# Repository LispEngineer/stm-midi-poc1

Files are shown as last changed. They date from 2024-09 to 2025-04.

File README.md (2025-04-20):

# MIDI Synthesizer Proof of Concept 1

**Feedback is very welcome!**

* Author: [Douglas P. Fields, Jr.](mailto:symbolics@lisp.engineer)
* My portions Copyright 2024 Douglas P. Fields, Jr.
* My portions License: Creative Commons Attribution-ShareAlike 4.0
  * AKA `CC BY-SA 4.0`
  * [See LICENSE.md](LICENSE.md) or [CC site](https://creativecommons.org/licenses/by-sa/4.0/deed.en)
* Started 2024-09-28
* Last updated 2025-04-20
* [Repo Self-Link](https://github.com/LispEngineer/stm-midi-poc1)

Overviews:
* 3D Views
  * Front 3D View
  * Rear 3D View
* [Schematic PDF](stm-midi-poc1.pdf)
* [Board Plots as PDF](plots/stm-midi-poc1__Assembly.pdf)
  * From Board2PDF KiCAD Plugin
* [Interactive BOM](bom/ibom.html)
  * From Interactive BOM KiCAD Plugin

Design documents:
* [Design notes](Design.md)
* Designed in [KiCAD 8](https://www.kicad.org/)
* LCSC part numbers included for assembly by [JLCPCB](https://jlcpcb.com/)

Debuggers:
* Segger J-Link EDU Mini
* Segger J-Link Plus v10.1 (second hand)
  * Built in VCOM port - only seems to work at 115,200 baud
* ST-Link v3
* FTDI USB to TTL UART

Software:
* [Pinout](https://github.com/LispEngineer/stm-midi-poc1-sw)
* [STM Synth](https://github.com/LispEngineer/nucleo-uart)
* [My KiCAD Libraries](https://github.com/LispEngineer/KiCAD_Libraries)

Discussions:
* [Smaller Optoisolator](https://www.reddit.com/r/synthdiy/comments/1gghujj/smaller_midi_optoisolator/)

## Key Reference Documents

* [DS11853](TODO) - Datasheet: Arm® Cortex®-M7 32b MCU+FPU, 462DMIPS, up to 512KB Flash
  256+16+4KB RAM, USB OTG HS/FS, 18 TIMs, 3 ADCs, 21 com IF
* [RM0431](TODO) - STM32F72xxx ... advanced Arm®-based 32-bit MCUs
* [PM0253](TODO) - STM32F7 Series ... Cortex®-M7 processor programming manual
* [ES0360](TODO) - STM32F72xxx ... device limitations
* [AN2867](TODO) - Guidelines for oscillator design on ... STM32 MCUs/MPUs
* [AN4661](TODO) - Getting started with STM32F7 Series MCU hardware development
* [AN5612](TODO) - ESD protection of STM32 MCUs
* [AN4879](TODO) - Introduction to USB hardware and PCB guidelines using STM32 MCUs
* [AN4989](TODO) - STM32 microcontroller debug toolbox
* [AN4676](TODO) - STM32F7 Series peripheral interconnections
* [AN4031](TODO) - Using the STM32F2, STM32F4 and STM32F7 Series DMA controller

Moving to STM32H7:
* [AN5293](TODO) - Migration guide from STM32F7 Series to STMH74x/75x, STM32H72x/73x and STMH7A3/7Bx devices
* [AN4936](TODO) - Migration of microcontroller applications from STM32F7 Series to STM32H743/753 line

# Production Runs

I have been using JLCPCB.

* [JLCPCB instructions](https://jlcpcb.com/help/article/how-to-generate-gerber-and-drill-files-in-kicad-8)
  on creating Gerber and Drill files for KiCAD 8.
* You can also use the
  [JLCPCB KiCAD plugin](https://github.com/Bouni/kicad-jlcpcb-tools).
  * Installed using the *Plugin and Content Manager* in KiCAD.
  * This usefully shows you the stock count for your parts, and whether
    they are Basic or Extended.
  * Current version (2024-12-21) gives a lot of errors about redundant
    parts already in the catalog though (annoying).
* Or maybe I was using [this JLCPCB KiCAD plugin](https://github.com/bennymeg/Fabrication-Toolkit).

## Run 1 - EVT#1

* Submitted: 2024-10-27
* Git Commit: `6f9e281abe9c22ef3b995376c3df42217fc04524`
* Producer: JLCPCB
  * Order #W202410271206812 
* Boards: 5
* Assemblies: 2
* [BOM](jlcpcb/production_files/BOM-stm-midi-poc1.csv)
* [CPL](jlcpcb/production_files/CPL-stm-midi-poc1.csv)
* [Gerbers](jlcpcb/production_files/GERBER-stm-midi-poc1.zip)
* JLCPCB Corrected Part Placement
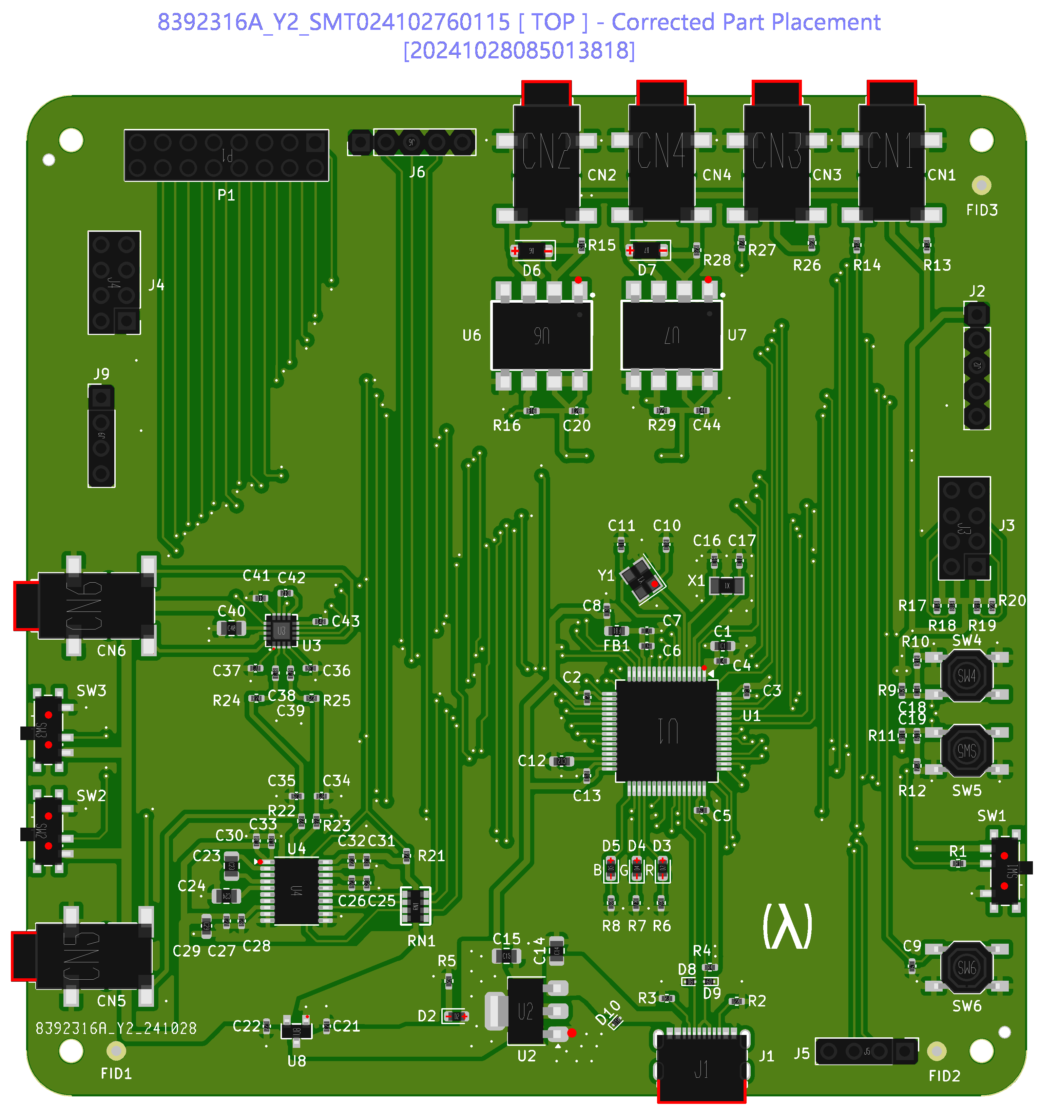
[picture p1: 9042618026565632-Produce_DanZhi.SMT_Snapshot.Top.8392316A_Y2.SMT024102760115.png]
  
* [JLCPCB Submission](jlcpcb-production/run1-20241027/stm-midi-poc1 6f9e281abe9c22ef3b995376c3df42217fc04524_Y2.zip)
* Status: Production complete; in DHL's hands for delivery Nov 8
* Cost:
  * PCB: $28.02
  * Assembly: $79.66
  * Shipping: $32.60 (DHL)
  * Sales tax: $11.22
  * Total: $151.50

I received two fully populated boards. One was missing the J5 header.

EVT1 Front Picture

## Run 2 - EVT#2

* Submitted: 2024-12-21 (11PM NYC time)
  * PCB and PCBA confirmed: 2024-12-22
* Git Commit: `e48a22093a1c81bb14c9082240e3d44837e7d75e`
* Producer: JLCPCB
* Order #W202412221204947 
* Boards: 5
* Assemblies: 2
* [BOM](jlcpcb/production_files/BOM-stm-midi-poc1.csv)
* [CPL](jlcpcb/production_files/CPL-stm-midi-poc1.csv)
* [Gerbers](jlcpcb/production_files/GERBER-stm-midi-poc1.zip)
* JLCPCB Corrected Part Placement
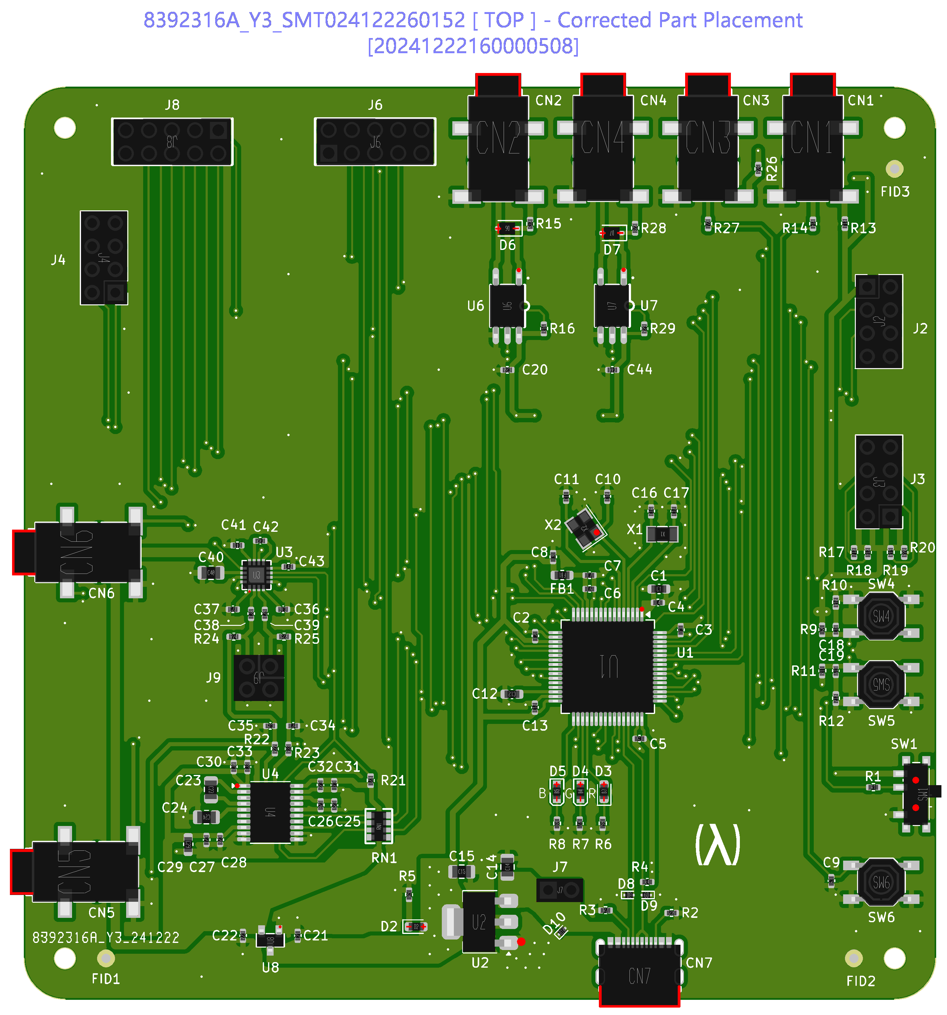
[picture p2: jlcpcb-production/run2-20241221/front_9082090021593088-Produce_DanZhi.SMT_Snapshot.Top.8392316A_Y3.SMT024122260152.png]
JLCPCB Corrected Part Placement
  
* [JLCPCB Submission](jlcpcb-production/run2-20241221/GERBER-stm-midi-poc1_Y3.zip)
* Status: Confirmed for PCB/PCBA
* Cost:
  * PCB: $8.00
  * Assembly: $86.40
  * Shipping: $58.36 (FedEx - "remote area" charge)
  * Sales tax: $12.22
  * Total: $164.98
* Received: 2025-01-03 (delivered on 2025-01-02)

Results:
* They did not add assembly holes this time (interesting, maybe re-used the mounting holes)
* STM32 Debugger (ST-Link v3) does not seem to reliably connect anymore.
  * It did allow me to download the firmware but is not reliable.
  * Sometimes it says "Failed to enable Live Expressions"
* SPI display works
* Audio Gain pins work
* Audio mute works
* Headphone output works
* Buttons & LEDs work

TODO:
* Test MIDI in/out
* Test Line out
* Test various resistors for the headphone
* Test I2C
* Test GPIO

# Miscellaneous Notes

* Footprints, models, etc., by their respective authors
* Some footprints, schematics, models are from these sources:
  * [Component Search Engine](https://componentsearchengine.com)
  * [Snap EDA](https://snapeda.com)
  * [EasyEDA](https://easyeda.com)
* Useful tools:
  * [EasyEDA2KiCAD](https://github.com/uPesy/easyeda2kicad.py)
  * [JLC Parts Finder](https://yaqwsx.github.io/jlcparts/)
  * [Altium Viewer](https://www.altium365.com/viewer/)
    * If you have Altium files and want to get details out of them
      but only use KiCAD

# KiCAD Configuration Notes

Using EasyEDA2KiCAD:

* Create a Path Substitution
  * Use main KiCAD window: Prefernces -> Configure Paths...
  * `EASYEDA2KICAD`
  * [Git Repository](https://github.com/LispEngineer/KiCAD_Libraries)
* Create a Footprint Library
  * `easyeda2kicad` Nickname
  * `${EASYEDA2KICAD}/easyeda2kicad.pretty`
* Create a Symbol Library
  * `easyeda2kicad` Nickname
  * `${EASYEDA2KICAD}/easyeda2kicad.kicad_sym` Library Path

# Status

* Schematic: Done
* LCSC part IDs: Almost Done
  * Need non-Red LEDs
* Schematic symbols: Done
* Footprints: Done
* 3D models: Done
* PCB Layout: Done
* Production 1 run: Done - in shipping

## TODOs

* Use STDC14 connector for ST-Link v3
  * Digikey [1175-1632-ND](https://www.digikey.com/en/products/detail/cnc-tech/3220-14-0300-00/3883270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)
    * Not in JLCPCB
  * Mouser [SHF-107-01-L-D-SM](https://www.mouser.com/ProductDetail/Samtec/SHF-107-01-L-D-SM?qs=%252BZP6%2F%252BtExtBY5XT826bN4g%3D%3D)
    * [Footprint](https://kinetictest.samtec.com/partnumber/shf-107-01-l-d-sm#featureinformation)
    * [JLCPCB C17640678](https://jlcpcb.com/partdetail/Samtec-SHF_107_01_L_DSM/C17640678) - $2???
    * [LCSC Alternative 1](https://www.lcsc.com/product-detail/Pin-Headers_Hanbo-Electronic-Hanbo-Electronic-HB-PH9-12727PB2GOB_C6332251.html) C6332251
    * [LCSC Alternative 2](https://www.lcsc.com/product-detail/Pin-Headers_HCTL-HCTL-PZ127-2-07-S_C3975190.html) C3975190 - 11¢
    * [LCSC Alternative 3](https://www.lcsc.com/product-detail/Pin-Headers_XKB-Connection-XKB-Connection-X1321WVS-2x07J-C40D53_C2881912.html) C2881912
* Use a 4-pin 32kHz clock?
* RN1 footprint and 3D model look a little bit off - footprint is a bit too small?
* Test points/pins
* MCU Pin 24 is not used - it is I2S1_MCK
* Incorporate my own ST-Link?
  * [See Hackaday](https://hackaday.io/project/179054-custom-st-link-v20-v21-v30)

### DONE

* DONE(EVT2): Find a much smaller Opto-isolator for MIDI than the one chosen here
  * [TLP2362](https://toshiba.semicon-storage.com/us/semiconductor/product/isolators-solid-state-relays/detail.TLP2362.html)
    is used by [Ksoloti 0.6](https://ksoloti.github.io/5-resources.html). Tested to work with
    1.8kΩ pull-up resistor instead of the schematic's 2.7kΩ.
    (Also worked with no pull-up resistor!)

# Board Layout Notes

4-layer design with Signal/GND/GND/Signal for EVT board.

Will do most important routing first on the top copper layer:
* Decoupling/bypass capacitors
* Clock signals
* High speed signals
  * USB
  * DAC
  * SWD

Remaining signals will be routed using "Manhattan routing."
That is, one signal layer will run up/down, the other will
run left/right, mostly.
* Top layer: up/down
* Bottom layer: left/right

After that, do these routings:
* Audio signals
* MIDI signals
* SPI
* I²C
* UI (Buttons, LEDs)
* GPIO
* Power

Fill in some positive power areas with fill.

Finally, the signal layers will be filled with GND at the end,
and the ground planes should be stitched together with lots
of vias.

## After Layout Is Done

* DRC check
* Cleanup Tracks & Vias

# BOM Notes

* Docs say you need a 4.7 uF ceramic capacitor with low ESR DS11853 Rev 9 page 105
  * Samsung CL10A475KO8NNNC works *but* Datasheet doesn't say what the ESR is, just "low ESR"
  * [Notes on the Cap](https://community.st.com/t5/stm32-mcus-products/how-supply-stm32f446ret6/td-p/635424)

* [ISOM8710](https://www.ti.com/product/ISOM8710) 
  is a drop-in replacement for the
  [TLP2362](https://toshiba.semicon-storage.com/us/semiconductor/product/isolators-solid-state-relays/detail.TLP2362.html)
  * Same form factor
  * Same functionality (tested on a breadboard)
  * Same circuit
  * Does not seem to be carried at JLCPCB

# Notes for future

* Use fewer header types, they're all extended parts
* Don't use the Resistor Network - due to the Extended parts fee from JLC
  * OTOH there are no 56Ω resistors in the Basic parts library
  * C25127 is an extended part 0402
  * C17714 is an 0805 47Ω
* Add I/O activity LEDs for MIDI & serial?
* Add a pin for VBUS (5V from USB) and USB GND
* Add pins for the TRS jacks
* Get a 4-way switch for gain?
* Rewrire the headphone amp like Pimoroni?
* Move console from UART3 to UART2
  * Move console pins next to SWD pins for easy use with STLink
* Install UART to USB bridge
  * [FTDI FT234XD](https://ftdichip.com/products/ft234xd/) is a nice 12-pin package
  * [Example Circuit](https://github.com/z4yx/USB-C-Serial)
  * [JLCPCB Part](https://jlcpcb.com/partdetail/Ftdi-FT234XDR/C132158)

Longer term
* Move to an STM32H7 device
* Move to a [higher pin-count device](https://www.st.com/en/microcontrollers-microprocessors/stm32h7-series/products.html)
  * LQFP 64, 100, 144, 176, 208
    * low-profile quad flat package - LQFP 64 currently in use
  * TFBGA 216, 225, 240+25
    * Thin Profile Fine Pitch Ball Grid Array
    * thinner than other BGA packages - Gemini
  * UFBGA 144, 169, 176+25
    * ultra fine pitch ball grid array
  * VFQFPN 68
    * thermally enhanced very thin profile fine pitch quad flat package no lead (Gemini)
  * WLCSP 132, 156
    * [Wafer-Level Chip Scale Packaging](https://www.flashpcb.com/blog/QFP-QFN-BGA-WLSCP)
* Add an SDRAM

# EasyEDA 2 KiCAD Notes

`python -m easyeda2kicad --full --lcsc_id=Cxxxxx`

[My imported library is in GitHub](https://github.com/LispEngineer/KiCAD_Libraries).

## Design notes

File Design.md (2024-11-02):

# Doug's MIDI Synth Board

* [Douglas P. Fields, Jr.](mailto:symbolics@lisp.engineer)
* Copyright 2024, Douglas P. Fields, Jr.
* License: Creative Commons Attribution-ShareAlike 4.0
  * AKA `CC BY-SA 4.0`
  * [See LICENSE.md](LICENSE.md) or [CC site](https://creativecommons.org/licenses/by-sa/4.0/deed.en)

Project Documentation:
* [Hardware requirements](https://docs.google.com/document/d/1ovH1onACyaObaqHR-o14pt8njggKNDry9VQSeMS2iqw/edit#heading=h.xvwzye5fndkg)

STM Hardware Development:
* [AN4661 Getting started with STM32F7 Series MCU hardware development](https://www.st.com/resource/en/application_note/an4661-getting-started-with-stm32f7-series-mcu-hardware-development-stmicroelectronics.pdf)
* [AN4938 Getting started with STM32H7{4,5}xI/G MCU hardware development](https://www.st.com/resource/en/application_note/an4938-getting-started-with-stm32h74xig-and-stm32h75xig-mcu-hardware-development-stmicroelectronics.pdf)
* [AN5419 Getting started with STM32H7{2,3}... Line hardware development](https://www.st.com/resource/en/application_note/an5419-getting-started-with-stm32h723733-stm32h725735-and-stm32h730-value-line-hardware-development-stmicroelectronic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)
* [AN4879 USB hardware and PCB guidlines using STM32 MCUs](TODO)
* [AN5225 Introduction to USB Type-C® Power Delivery](TODO)
  * See Section 10 - `Type C with no Power Delivery`

STM Documents:
* [DS11853 Rev 9 - STM32F2{2,3}xx Datasheet](TODO)

STM Discussions:
* [Forum: Recommended schematic review](https://community.st.com/t5/stm32-mcus/how-to-conduct-a-stm32-self-schematic-review-pt-1/ta-p/49593)
  * [Part 2](https://community.st.com/t5/stm32-mcus/how-to-conduct-a-stm32-self-schematic-review-pt-2/ta-p/49595)
* [StackOverflow STM32](https://electronics.stackexchange.com/questions/611915/schematic-review-for-stm32-basic-development-board)
* [STM32 Design in KiCAD](https://vivonomicon.com/2018/05/05/your-own-hardware-designing-an-stm32-development-board/)

Schematic References:
* [Ksoloti Core 0.6](https://github.com/ksoloti/ksoloti)
  * [STM32F429ZGT6 (LQFP 144)](https://www.st.com/en/microcontrollers-microprocessors/stm32f429zg.html#overview) with SDRAM
  * [Schematics](https://ksoloti.github.io/5-resources.html)
* [Daisy Seed](TODO) - schematic not available
* [Teensy 4.1](TODO) - Renesas, not STM32
* [Blue Pill](https://stm32-base.org/boards/STM32F103C8T6-Blue-Pill.html)
  * [More on Blue Pill](https://www.hackster.io/MakerIoT2020/remaking-the-stm32-blue-pill-d3ae30)
* [Pimoroni Pico Audio Pack PIM544](https://shop.pimoroni.com/products/pico-audio-pack?variant=32369490853971)
  * [Pimoroni Pico Audio Pack PIM544 Schematic](https://cdn.shopify.com/s/files/1/0174/1800/files/pico_audio_pack_schematic.pdf?v=1647429199)
  * [PCM5102A I2S DAC](https://www.ti.com/product/PCM5102A)
  * [PCM5102 and STM32](http://elastic-notes.blogspot.com/2020/11/use-pcm5102-with-stm32_76.html)
  * [Wikipedia I²S](https://en.wikipedia.org/wiki/I%C2%B2S)
* [ubld.it MIDI-Mini Breakout Board](https://ubld.it/midi-mini)

# Schematic Notes

* Using STM32F722xx with LQFP64 pinout

* Vbat - See DS11853 Rev 9 - Connect to "VDD when no external battery 
  and [no] external super-capacitor are present."

## USB-C in 2.0 Mode

* [Wiring post](https://www.eevblog.com/forum/projects/usb-type-c-(usb2-0)-wiring/)
  - A6 to B6 (D+) to D+ on the micro
  - A7 to B7 (D-) to D- on the micro
  - A4 to A9 to B4 to B9 (VBUS) to VCC (+5V) on the micro
  - A5 (CC1) to GND via 5k1 Resistor
  - B5 (CC2) to GND via another 5k1 Resistor
  - A1 to A12 to B1 to B12 (GND) to Ground
* [Another wiring post](https://www.eevblog.com/forum/projects/minimal-wiring-for-usb-c-jack/)
* [Kicad Post](https://forum.kicad.info/t/how-to-connect-a-ft232rl-to-a-usb-type-c-connector/18557/2)
* Where is the official specification for this?
* [GND & Shield](https://electrical.codidact.com/posts/279876/285004#answer-285004)

## Power

* [STM LD1117](https://www.st.com/resource/en/datasheet/ld1117.pdf) - 800mA
* [STM LD39050](https://www.st.com/resource/en/datasheet/ld39050.pdf) - 500mA
* [AMS1117-3.3](http://www.advanced-monolithic.com/pdf/ds1117.pdf) - 1A
* [AP2161](https://www.digikey.com/en/products/base-product/diodes-incorporated/31/AP2161/66238)
  * C176957 & C2149802

## Misc Components

* Ferrite Bead: 
* [16 MHz Oscillator](https://jlcpcb.com/partdetail/YangxingTech-X322516MMB4SI/C112972)
* USB-C ESD Protection: STM USBLC6-2
* [32k Crystal Notes](https://community.st.com/t5/stm32-mpus-products/lse-crystal-for-st32mp1-fc-135-38-768-khz/td-p/679119)
  * [Phil's Lab Math](https://youtu.be/aVUqaB0IMh4?t=1619&si=jmx2GFCgxkBLzdWy)
  * Load Capacitors
  * 7pF osc
  * Estimate 3-5pF of stray capacitance
  * 7 - 5 = 2 x 2 = 4 pF
  * 7 - 3 = 4 x 2 = 8 pF
  * 7 - 4 = 3 x 2 = 6 pF
* [Push Button Wiring](https://www.youtube.com/watch?v=JZsC34jfbEg)
* [TRS MIDI](https://midi.org/specification-for-use-of-trs-connectors-with-midi-devices)
* [ubld.it MIDI Breakout Schematic](https://ubld.it/wp-content/uploads/2023/10/MIDI_BOB_MV_Mini_Schematic_RevA.pdf)
* [DeftAudio Teensy MIDI Schematic](blob:https://github.com/08e4b098-b5fc-4c80-bbc1-2535837214dd)
* [Component Search Engine](https://componentsearchengine.com/)
* [JLC Component Catalog](https://yaqwsx.github.io/jlcparts/#/) Third party tool
* Resettable fuse: SMD0603-200L

## Opto-Isolator Alternatives

* [Toshiba TLP2361](https://toshiba.semicon-storage.com/us/semiconductor/product/isolators-solid-state-relays/detail.TLP2361.html)
  * Package: SOIC-6
  * [Mouser](https://www.mouser.com/ProductDetail/Toshiba/TLP2361TPLE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)
  * [LCSC](https://www.lcsc.com/product-detail/Optocouplers---Logic-Output_TOSHIBA-TOSHIBA-TLP2361V4-TPL%2CE_C123773.html)
  * "if you need to save space, use a SO-5 chip like the TLP2361 (which has a CMOS output, so it does not need a pull-up resistor)" [source](https://electronics.stackexchange.com/questions/165255/midi-in-many-circuits)
* [Toshiba TLP2362](https://toshiba.semicon-storage.com/us/semiconductor/product/isolators-solid-state-relays/detail.TLP2362.html)
  * Used by Ksoloti - see their schematic
* [Vishay VO0600](https://www.vishay.com/en/product/84607/)
  * Package: SOIC-8
  * [LCSC](https://www.lcsc.com/product-detail/Logic-Output-Optoisolators_Vishay-Intertech-VO0600T_C5830851.html)
  * [Mouser](https://www.mouser.com/ProductDetail/Vishay-Semiconductors/VO0600T?qs=xCMk%252BIHWTZMQ6VardsKvcQ%3D%3D)
* [TI ISOM8710](https://www.ti.com/product/ISOM8710)
  * Package: SOIC-5
  * [Mouser](https://www.mouser.com/ProductDetail/Texas-Instruments/ISOM8710DFFR?qs=1Kr7Jg1SGW%2Fig%2FeXrQnwtQ%3D%3D)
  * [LCSC](https://www.lcsc.com/product-detail/Modules_Texas-Instruments-ISOM8710DFFEVM_C17217617.html) -
    not currently available
* [TI ISOM8711](https://www.ti.com/product/ISOM8711)
  * Package: SOIC-5
  * [Mouser](https://www.mouser.com/ProductDetail/Texas-Instruments/ISOM8711DFFR?qs=HoCaDK9Nz5f4%252B%2FwLVK60Ow%3D%3D)
  * [LCSC](https://www.lcsc.com/product-detail/Optocoupler-Emulator-Optocoupler-Replacement_Texas-Instruments-ISOM8711DFFR_C22399679.html) - 
    not currently available
* [TI ISOM8110]() - also look at ISOM8115
  * Package: SOIC-4
  * [LCSC](https://www.lcsc.com/product-detail/Optocoupler-Emulator-Optocoupler-Replacement_Texas-Instruments-ISOM8110DFGR_C22431318.html) -
    not currently available
  * [Mouser](https://www.mouser.com/ProductDetail/Texas-Instruments/ISOM8110DFGRQ1?qs=IKkN%2F947nfCR7%2Fv949luTw%3D%3D)
  * [Mouser 8115](https://www.mouser.com/ProductDetail/Texas-Instruments/ISOM8115DFGRQ1?qs=olJun0bQHM8UNDPuYUCEKw%3D%3D)
* [H11L1]()
  * Available in DIP models, e.g., PDIP-6
  * Mouser doesn't stock Everlight models
  * [Mouser OnSemi H11L1M](https://www.mouser.com/ProductDetail/onsemi-Fairchild/H11L1M?qs=P36CEcFBmYxn5ViwkIckpw%3D%3D)
  * Everlight [LCSC](https://www.lcsc.com/product-detail/Logic-Output-Optoisolators_Everlight-Elec-H11L1S-TA_C78589.html) - plenty in stock, SMD

# DF0997 UART/I2C Display

I tested this with an FT-232 and RealTerm on Windows.
[GitHub](https://github.com/DFRobot/DFRobot_LcdDisplay)
has library source code. [Wiki](https://wiki.dfrobot.com/_SKU_DFR0997_I2C_UART_2_inch_Color_Serial_Command_Screen#target_16)
has documentation.

* UART: 9,600 bps 8-N-1
  * I tried 57,600 but it seems fixed at 9,600
* Clear screen: 0x55 0xAA 0x01 0x1D
* Draw a black pixel: 0x55 0xAA 0x0E 0x02 0x00 0x00 0x00 0x00 0x60 0x00 0x60 0xFF 0xFF 0xFF 0xFF 0xFF 0xFF
* Set background color to green: 0x55 0xAA 0x04 0x19 0x00 0xFF 0x00
  * This keeps the various black pixels still black (!)
* If you plug in a USB-C to your Windows computer, it shows up as 
  a USB drive with 8MB capacity
  * Lots of `.png` files in various directories
  * They call this the "U-Disk"

# KiCAD 8 Notes

## Plugins

* [JLC PCB Fabrication Toolkit](https://github.com/bennymeg/Fabrication-Toolkit)
* [KiCAD JLCPCB tools](https://github.com/Bouni/kicad-jlcpcb-tools)
* Alternate Kicad Library
* Generic Symbol Library
* 4ms Kicad Libraries
* Schematic Blocks Plug-In
* Simple Libraries
* Git plugin
* PCBWay
  * Fabrication Toolkit
  * Plug-in for KiCad

## EasyEDA imports

* Use [this tool](https://github.com/uPesy/easyeda2kicad.py)

## Copper Zones

* After placing them, you have to calculate their fills
  before they'll do anything!
  * Hit `b` hotkey

# Git for Windows notes

## Powershell

* `start-ssh-agent.cmd`

# JLCPCB Notes

Using the JLCDFM automated analyzer:

* Silkscreen line width needs to be > 0.15mm
  * This means a lot of letters are too thin by default
* Ensure that silkscreen does not cover any holes
* Have at least 3.05mm from any through hole components to
  SMD components (THT to SMD)
* Slot widths have to be 0.81mm
  * The USB-C slots seem to be 0.6mm
* All Vias are warned as unconnected
* The micro and Ohm unicode symbols do not import into JLCPCB BOM properly

KiCAD 8 notes:
* Create a special field for JLCPCB manufacturing:
  * File -> Schematic Setup → General → Field Name Templates
  * LCSC - JLC PCB Part number
  * DPFNOTES - Doug's notes on the part
  * DPFURL - URL to a spec sheet on the part

Utilities:
* [Component Catalog](https://yaqwsx.github.io/jlcparts/#/) - 3rd party site
* [Importer](https://forum.kicad.info/t/post-v7-new-features-and-development-news/40144/29)
* [EasyEDA loader](https://forum.kicad.info/t/footprints-from-jlcpcb/47051/8)

# JLCPCB Components

Components:
* [STM32F722RET6](https://jlcpcb.com/partdetail/Stmicroelectronics-STM32F722RET6/C118207)
  * LCSC C118207
* [Mini pushbutton](https://jlcpcb.com/partdetail/XkbConnection-TS_1187A_B_AB/C318884)
  * Mfr TS-1187A-B-A-B XKB
  * LCSC C318884
* [32k Crystal](https://jlcpcb.com/partdetail/SeikoEpson-Q13FC13500004/C32346)
  * LCSC C32346

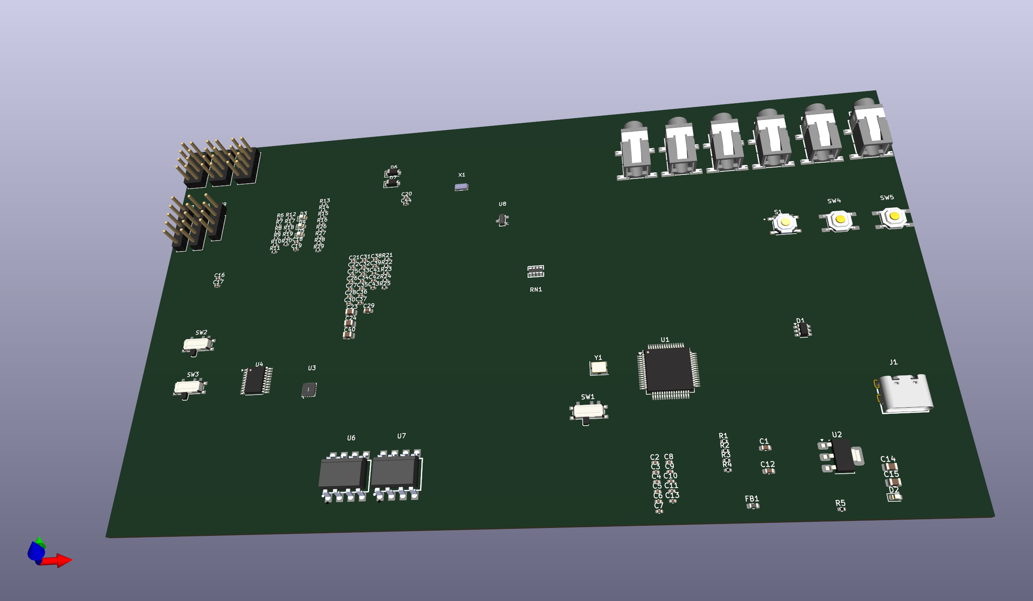
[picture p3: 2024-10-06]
stm-midi-poc1-pcb1.png

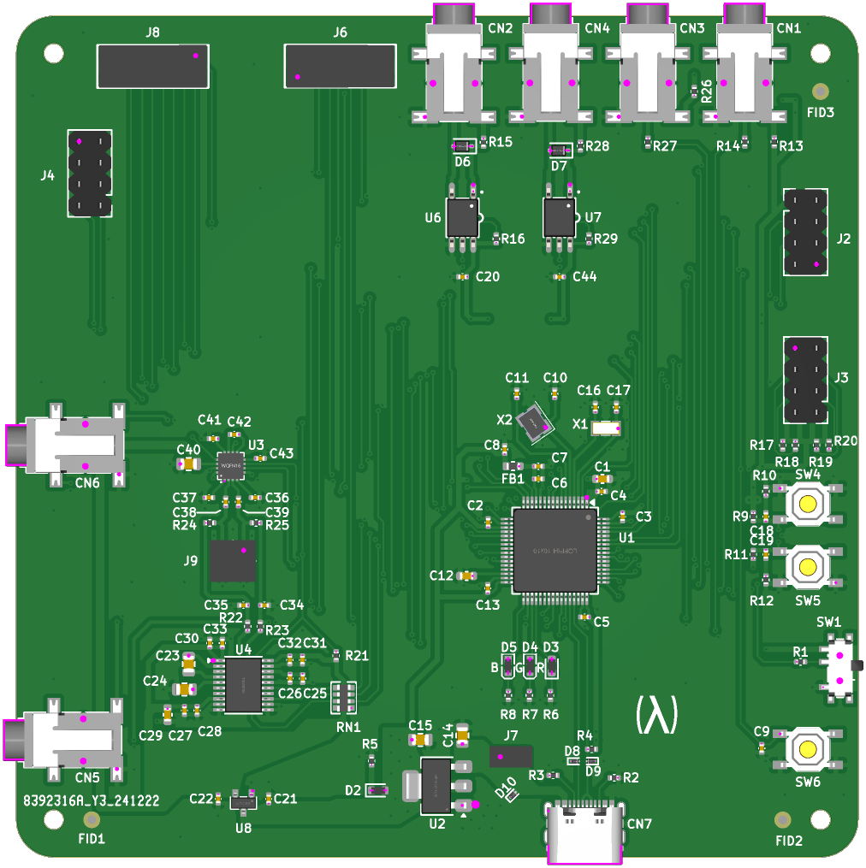
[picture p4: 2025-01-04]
top_12_22_2024, 10_15_21 AM.png

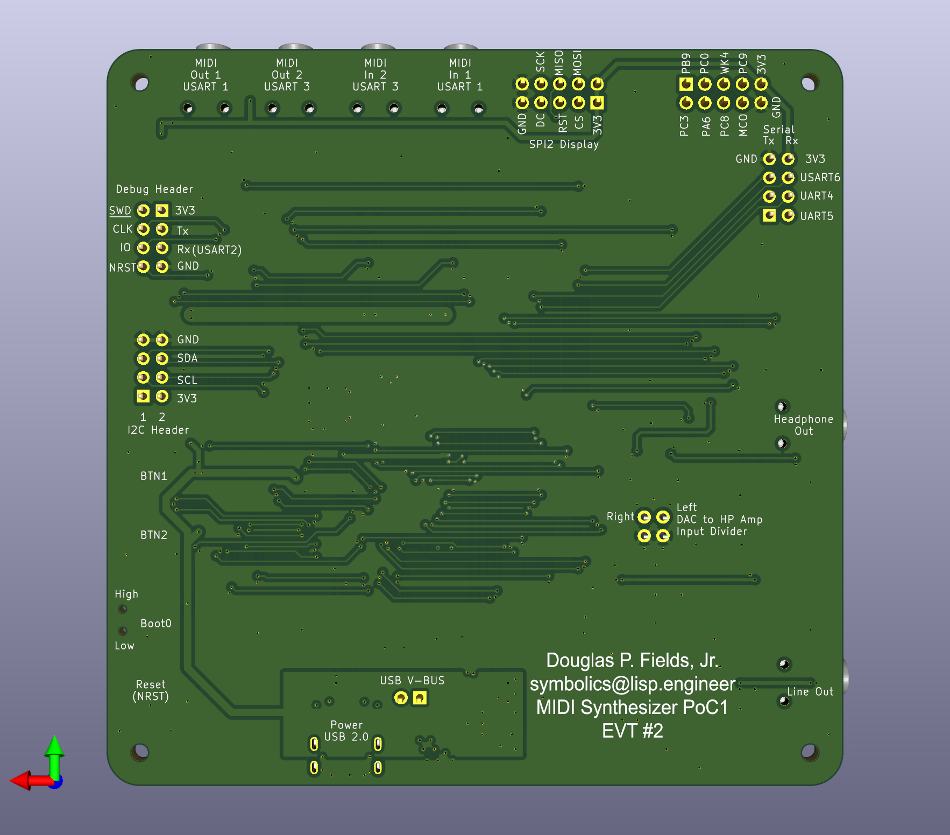
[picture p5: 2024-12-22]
stm-midi-poc1-3d-rear-head-on.png

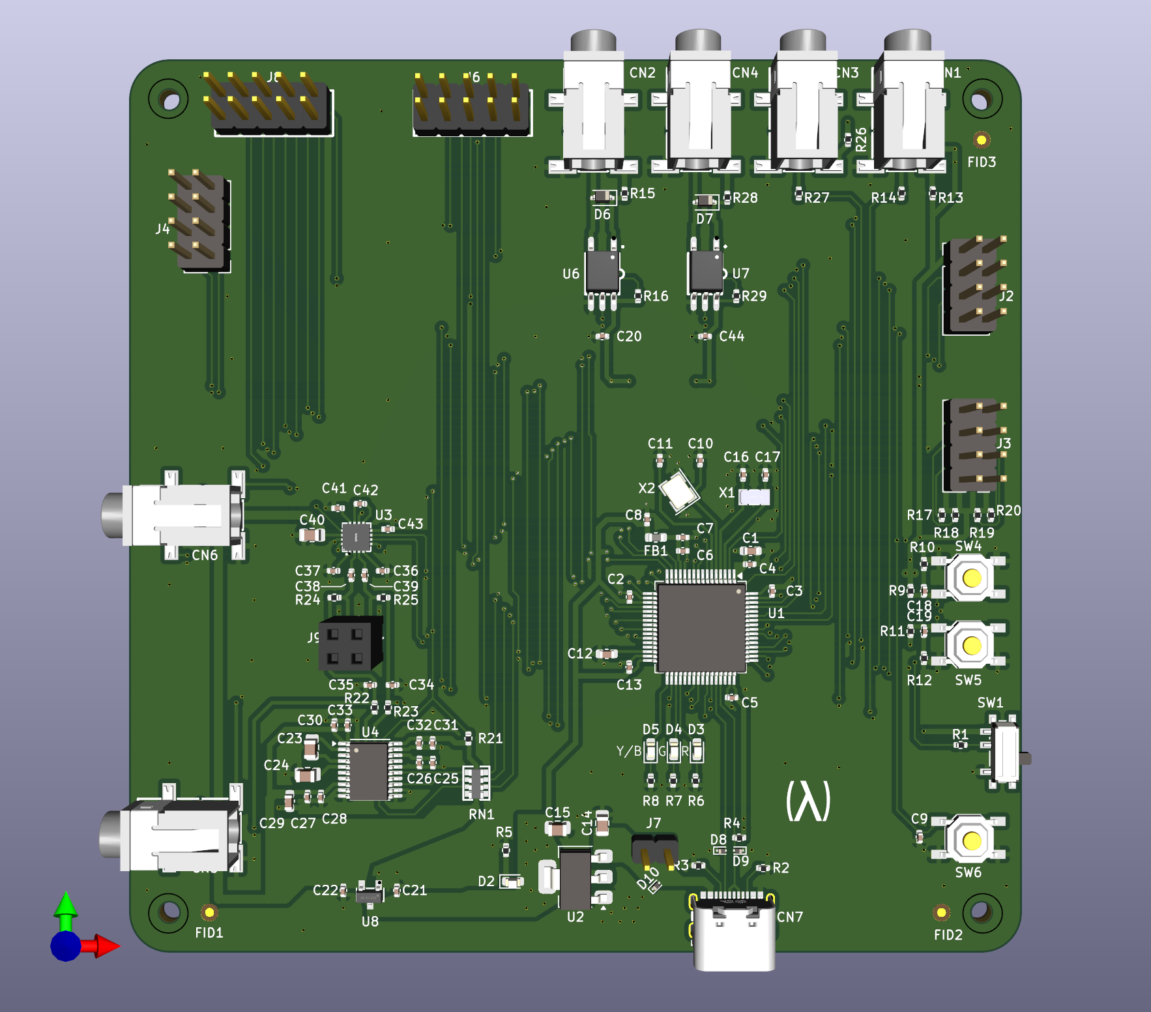
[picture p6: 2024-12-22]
stm-midi-poc1-3d-front-head-on.png

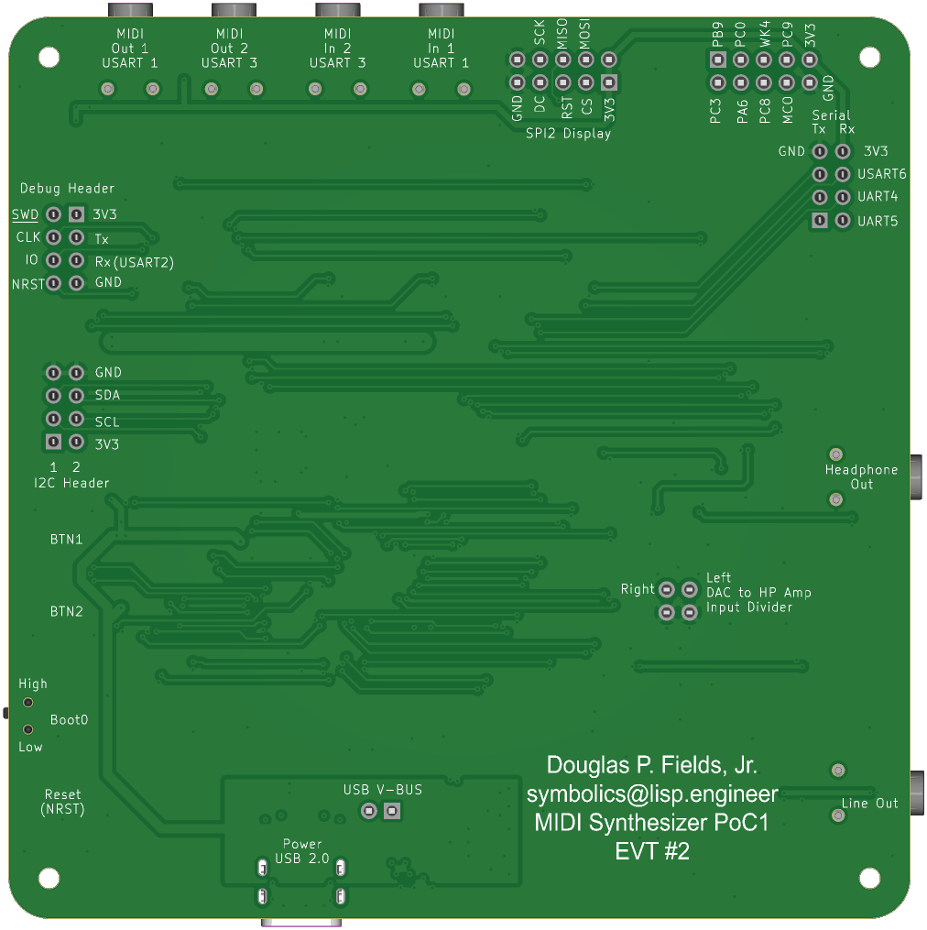
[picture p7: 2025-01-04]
bottom_12_22_2024, 10_15_21 AM.png

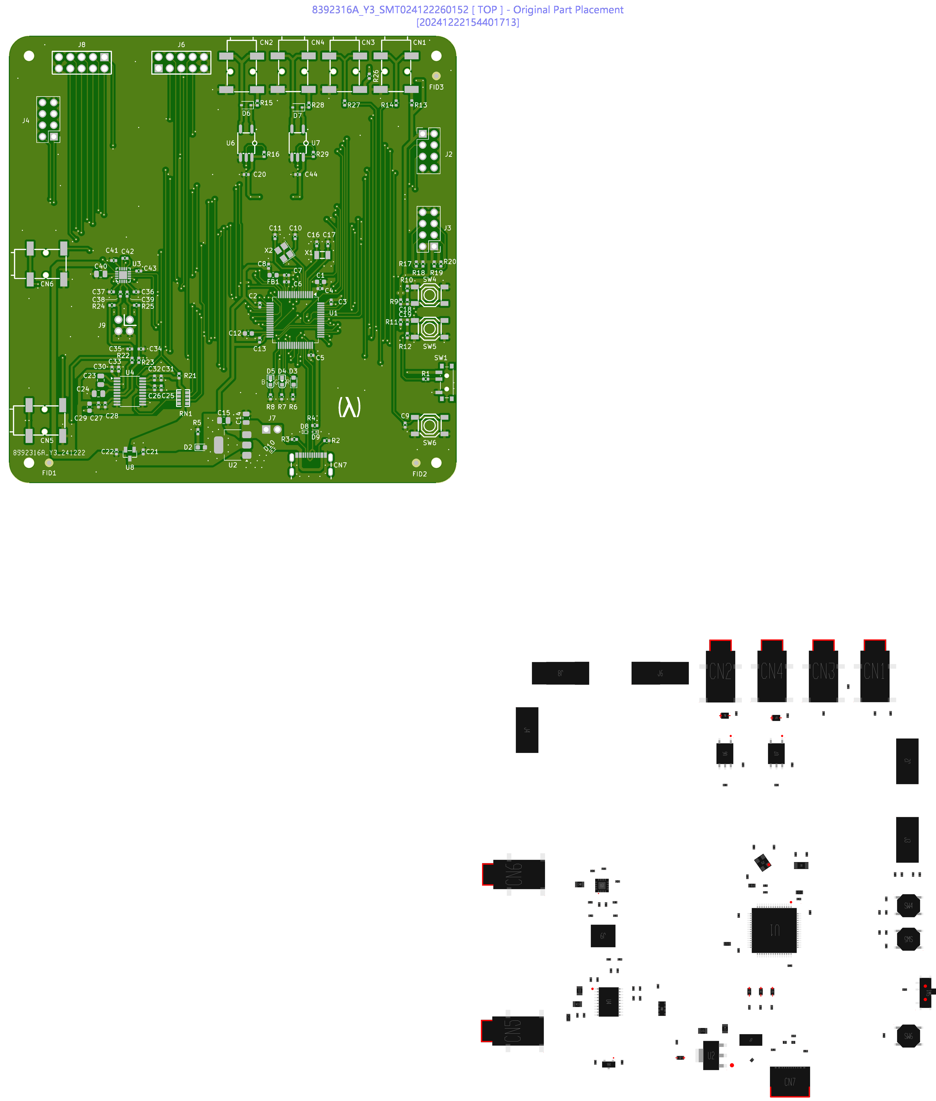
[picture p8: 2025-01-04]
5695488-Produce_DanZhi.SMT_Original_Snapshot.Top.8392316A_Y3.SMT024122260152.png

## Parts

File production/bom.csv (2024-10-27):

Designator | Footprint | Quantity | Value | LCSC Part #
C1, C29 | 0603 | 2 | 10uF | C96446
C10, C11 | 0402 | 2 | 10pF | C32949
C12 | 0603 | 1 | 4.7uF | C19666
C13, C18, C19, C2, C20, C26, C28, C3, C32, C33, C4, C44, C5, C9 | 0402 | 14 | 100nF | C307331
C14, C15 | 0805 | 2 | 22uF | C45783
C16, C17 | 0402 | 2 | 4.7pF | C1569
C21, C22, C25, C27, C30, C31, C36, C37, C38, C39, C41, C42, C43, C7, C8 | 0402 | 15 | 1uF | C52923
C23, C24, C40 | 0805 | 3 | 2.2uF | C377773
C34, C35, C6 | 0402 | 3 | 10nF | C15195
CN1 | AUDIO-SMD_PJ-321A-4A | 1 | MIDI Out 1 | C879743
CN2 | AUDIO-SMD_PJ-321A-4A | 1 | MIDI In 1 | C879743
CN3 | AUDIO-SMD_PJ-321A-4A | 1 | MIDI Out 2 | C879743
CN4 | AUDIO-SMD_PJ-321A-4A | 1 | MIDI In 2 | C879743
CN5 | AUDIO-SMD_PJ-321A-4A | 1 | Line out | C879743
CN6 | AUDIO-SMD_PJ-321A-4A | 1 | Headphone | C879743
D10, D8, D9 | D_SOD-923 | 3 | ESD | C111566
D2 | 0603 | 1 | RED_PWR | C2286
D3 | 0603 | 1 | USER_RED | C2286
D4 | 0603 | 1 | USER_GREEN | C72043
D5 | 0603 | 1 | USER_BLUE | C72038
D6, D7 | D_SOD-123 | 2 | 1N4148W | C81598
FB1 | 0603 | 1 | 120@100MHz | C133937
J1 | USB-C-SMD_GT-USB-7010I | 1 | GT-USB-7010I | C5362630
J2 | PinHeader_1x05_P2.54mm_Vertical | 1 | SWD | C7430361
J3 | PinHeader_2x04_P2.54mm_Vertical | 1 | I2C | C5156676
J4 | PinHeader_2x04_P2.54mm_Vertical | 1 | UART46 | C5156676
J5 | PinHeader_1x04_P2.54mm_Vertical | 1 | UART5 | C5116483
J6 | PinHeader_1x05_P2.54mm_Vertical | 1 | SPI | C7430361
J9 | PinHeader_1x04_P2.54mm_Vertical | 1 | Serial | C5116483
P1 | HDR-TH_16P-P2.54-V-M-R2-C8-S2.54 | 1 | GPIO | C68234
R1, R21 | 0402 | 2 | 10kΩ | C25744
R10, R12 | 0402 | 2 | 100Ω | C25076
R11, R9 | 0402 | 2 | 4k7Ω | C25900
R13, R14, R26, R27 | 0402 | 4 | 47Ω | C25118
R15, R22, R23, R28 | 0402 | 4 | 220Ω | C25091
R16, R29 | 0402 | 2 | 470Ω | C25117
R17, R18, R19, R20 | 0402 | 4 | 1k8Ω | C25871
R2, R3 | 0402 | 2 | 5k1Ω | C25905
R24, R25 | 0402 | 2 | 3k9Ω 1% | C51721
R4, R5, R6, R7, R8 | 0402 | 5 | 1k5Ω | C25867
RN1 | RES-ARRAY-SMD_0603-8P-L3.2-W1.6-BL | 1 | 56Ω | C25512
SW1 | SW_SPDT_PCM12 | 1 | BOOT0 | C109335
SW2 | SW_SPDT_PCM12 | 1 | Gain0 | C109335
SW3 | SW_SPDT_PCM12 | 1 | Gain1 | C109335
SW4 | SW-SMD_4P-L5.1-W5.1-P3.70-LS6.5-TL-2 | 1 | BTN1 | C318884
SW5 | SW-SMD_4P-L5.1-W5.1-P3.70-LS6.5-TL-2 | 1 | BTN2 | C318884
SW6 | SW-SMD_4P-L5.1-W5.1-P3.70-LS6.5-TL-2 | 1 | Reset | C318884
U1 | LQFP-64_10x10mm_P0.5mm | 1 | STM32F722RETx | C118207
U2 | SOT-223-3_TabPin2 | 1 | AMS1117-3.3 | C6186
U3 | QFN-16_L3.0-W3.0-P0.50-BL-EP1.7 | 1 | PAM8908JER | C33233
U4 | TSSOP-20_4.4x6.5mm_P0.65mm | 1 | PCM5102A | C107671
U6, U7 | SOP-8_L9.8-W6.6-P2.54-LS10.3-BL | 2 | 6N137S-TA1 | C92651
U8 | SOT-23-3_L2.9-W1.3-P1.90-LS2.4-BR | 1 | AP7333-33SRG-7 | C150745
X1 | FC-135R_L3.2-W1.5 | 1 | 32.768kHz 7pF | C48615
Y1 | Crystal_SMD_3225-4Pin_3.2x2.5mm | 1 | 16MHz 10pF | C112972

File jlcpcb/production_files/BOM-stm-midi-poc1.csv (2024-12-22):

Comment | Designator | Footprint | LCSC | Quantity
PCM5102A | U4 | TSSOP-20_4.4x6.5mm_P0.65mm | C107671 | 1
BOOT0 | SW1 | SW_SPDT_PCM12 | C109335 | 1
ESD | D10,D8,D9 | D_SOD-923 | C111566 | 3
16MHz 10pF | X2 | Crystal_SMD_3225-4Pin_3.2x2.5mm | C112972 | 1
STM32F722RETx | U1 | LQFP-64_10x10mm_P0.5mm | C118207 | 1
120@100MHz | FB1 | L_0603_1608Metric | C133937 | 1
AP7333-33SRG-7 | U8 | SOT-23-3_L2.9-W1.3-P1.90-LS2.4-BR | C150745 | 1
10nF | C34,C35,C6 | C_0402_1005Metric | C15195 | 3
4.7pF | C16,C17 | C_0402_1005Metric | C1569 | 2
USER_GREEN | D4 | LED0603-RD | C19189745 | 1
4.7uF | C12 | C_0603_1608Metric | C19666 | 1
1N4148WS | D6,D7 | D_SOD-323 | C2128 | 2
RED_PWR | D2,D3 | LED_0603_1608Metric | C2286 | 2
USER_BLUE | D5 | LED0603-RD | C2288 | 1
100Ω | R10,R12 | R_0402_1005Metric | C25076 | 2
220Ω | R15,R22,R23,R28 | R_0402_1005Metric | C25091 | 4
47Ω | R13,R14,R26,R27 | R_0402_1005Metric | C25118 | 4
56Ω | RN1 | RES-ARRAY-SMD_0603-8P-L3.2-W1.6-BL | C25512 | 1
10kΩ | R1,R21 | R_0402_1005Metric | C25744 | 2
1k5Ω | R4,R5,R6,R7,R8 | R_0402_1005Metric | C25867 | 5
1k8Ω | R16,R17,R18,R19,R20,R29 | R_0402_1005Metric | C25871 | 6
4k7Ω | R11,R9 | R_0402_1005Metric | C25900 | 2
5k1Ω | R2,R3 | R_0402_1005Metric | C25905 | 2
Input Divider | J9 | HDR-TH_4P-P2.54-V-F-R2-C2-S2.54 | C2977590 | 1
100nF | C13,C18,C19,C2,C20,C26,C28,C3,C32,C33,C4,C44,C5,C9 | C_0402_1005Metric | C307331 | 14
BTN1 | SW4,SW5,SW6 | SW-SMD_4P-L5.1-W5.1-P3.70-LS6.5-TL-2 | C318884 | 3
10pF | C10,C11 | C_0402_1005Metric | C32949 | 2
PAM8908JER | U3 | QFN-16_L3.0-W3.0-P0.50-BL-EP1.7 | C33233 | 1
TLP2362 | U6,U7 | OPTO-SMD-5_L3.7-W4.6-P1.27-LS7.0-BR | C37658 | 2
2.2uF | C23,C24,C40 | C_0805_2012Metric | C377773 | 3
22uF | C14,C15 | C_0805_2012Metric | C45783 | 2
32.768kHz 7pF | X1 | FC-135R_L3.2-W1.5 | C48615 | 1
Debug | J2,J3,J4 | PinHeader_2x04_P2.54mm_Vertical | C5156676 | 3
SPI | J6,J8 | HDR-TH_10P-P2.54-V-M-R2-C5-S2.54-1 | C5156677 | 2
3k9Ω 1% | R24,R25 | R_0402_1005Metric | C51721 | 2
1uF | C21,C22,C25,C27,C30,C31,C36,C37,C38,C39,C41,C42,C43,C7,C8 | C_0402_1005Metric | C52923 | 15
USB-C | CN7 | USB-C-SMD_GT-USB-7010I | C5362630 | 1
USB-5V | J7 | HDR-TH_2P-P2.54-V-M-1 | C5383111 | 1
AMS1117-3.3 | U2 | SOT-223-3_TabPin2 | C6186 | 1
MIDI Out 1 | CN1,CN2,CN3,CN4,CN5,CN6 | AUDIO-SMD_PJ-321A-4A | C879743 | 6
10uF | C1,C29 | C_0603_1608Metric | C96446 | 2

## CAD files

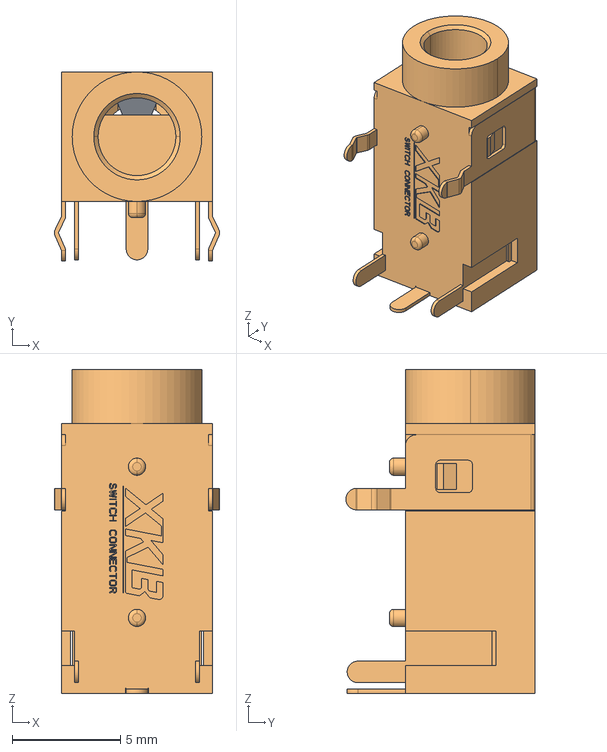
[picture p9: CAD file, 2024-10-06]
PJ-321B.stp
7.66 x 8.76 x 15.0 mm

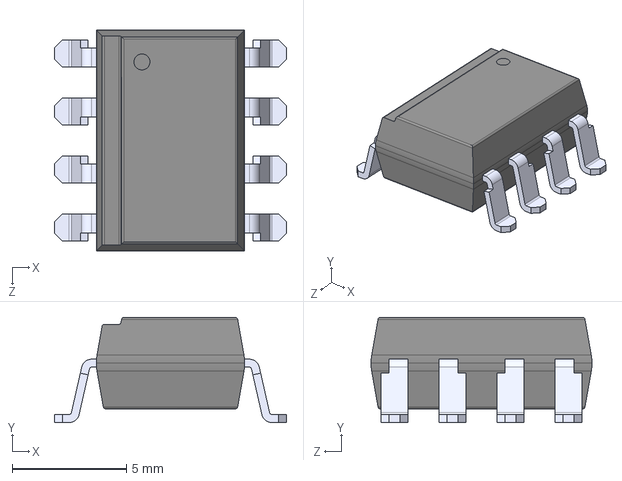
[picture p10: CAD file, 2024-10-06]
6N137S-TA1.stp
10.2 x 4.60 x 9.68 mm

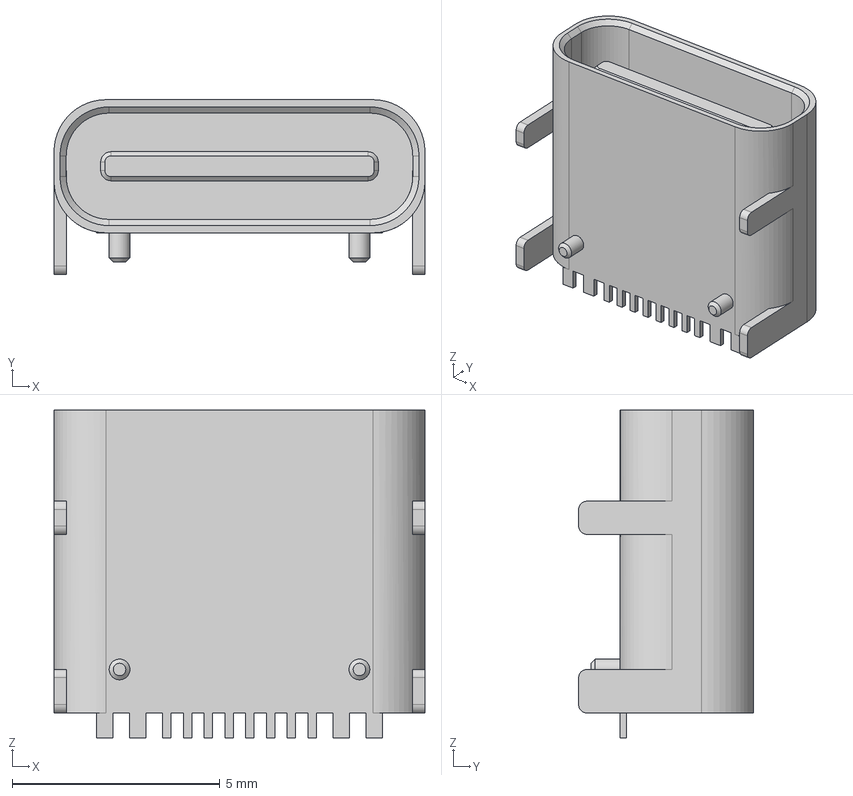
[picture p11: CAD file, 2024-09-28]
HRO TYPE-C-31-M-12.step
8.94 x 4.21 x 7.90 mm

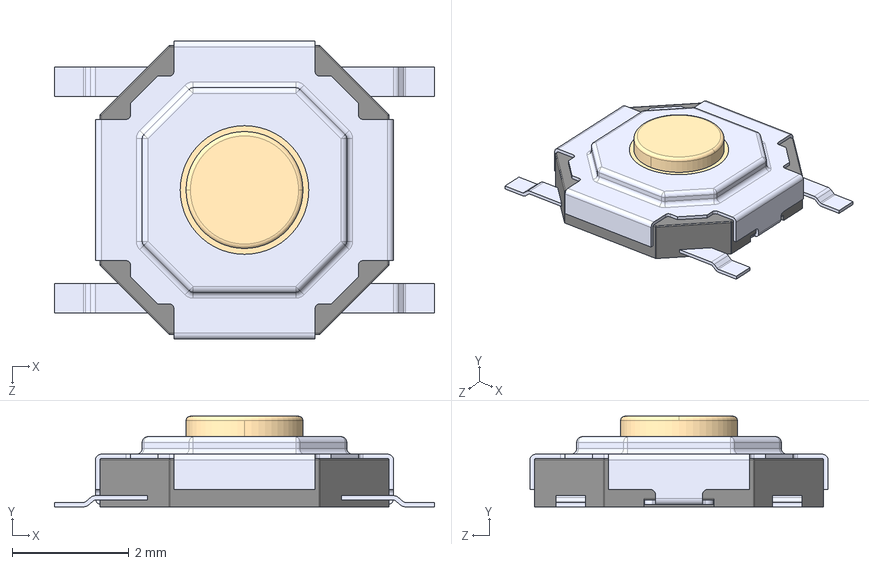
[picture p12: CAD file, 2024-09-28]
TS-1187A-B-A-B.step
6.50 x 1.55 x 5.10 mm

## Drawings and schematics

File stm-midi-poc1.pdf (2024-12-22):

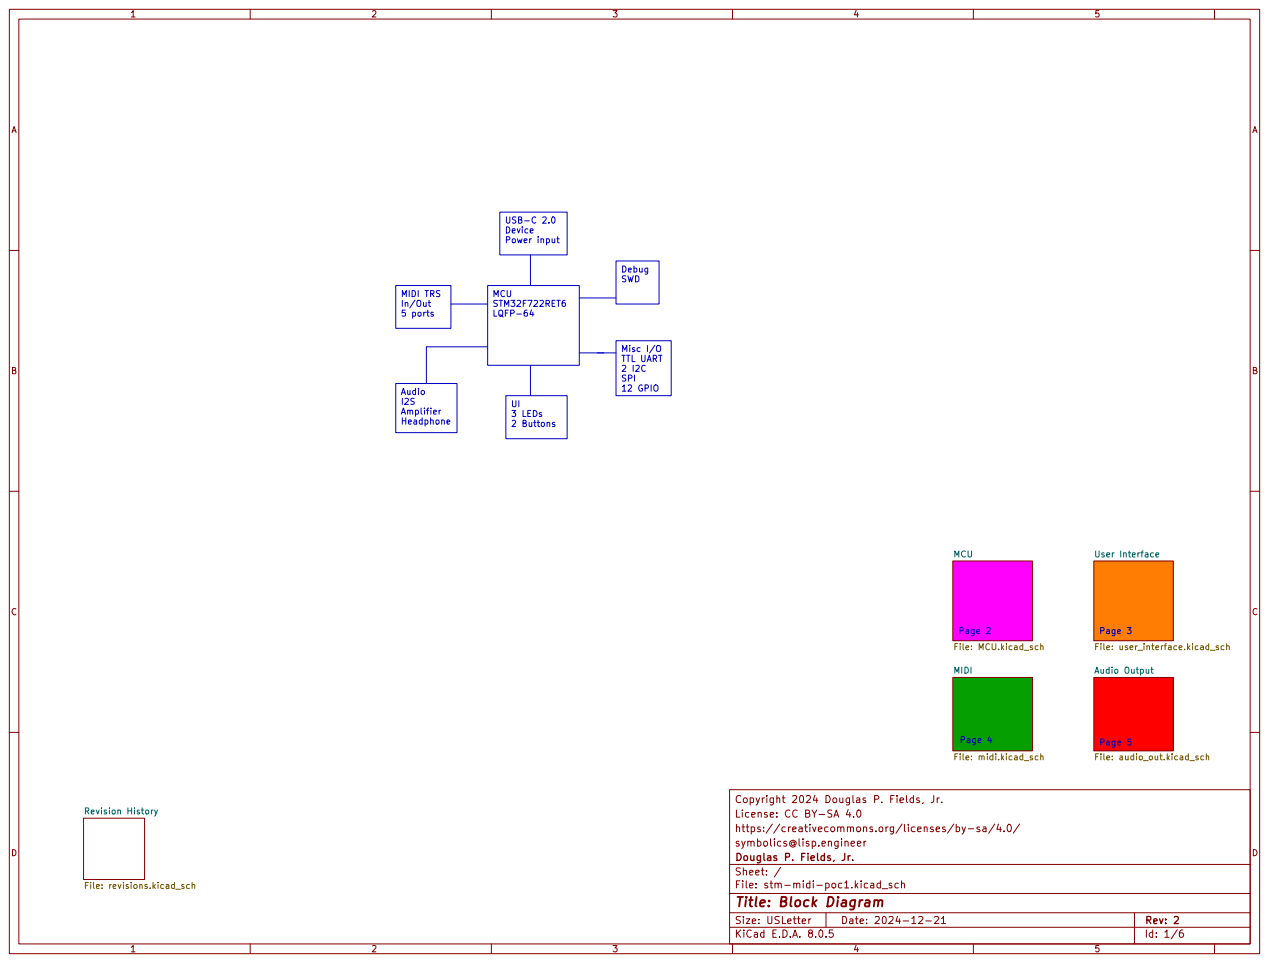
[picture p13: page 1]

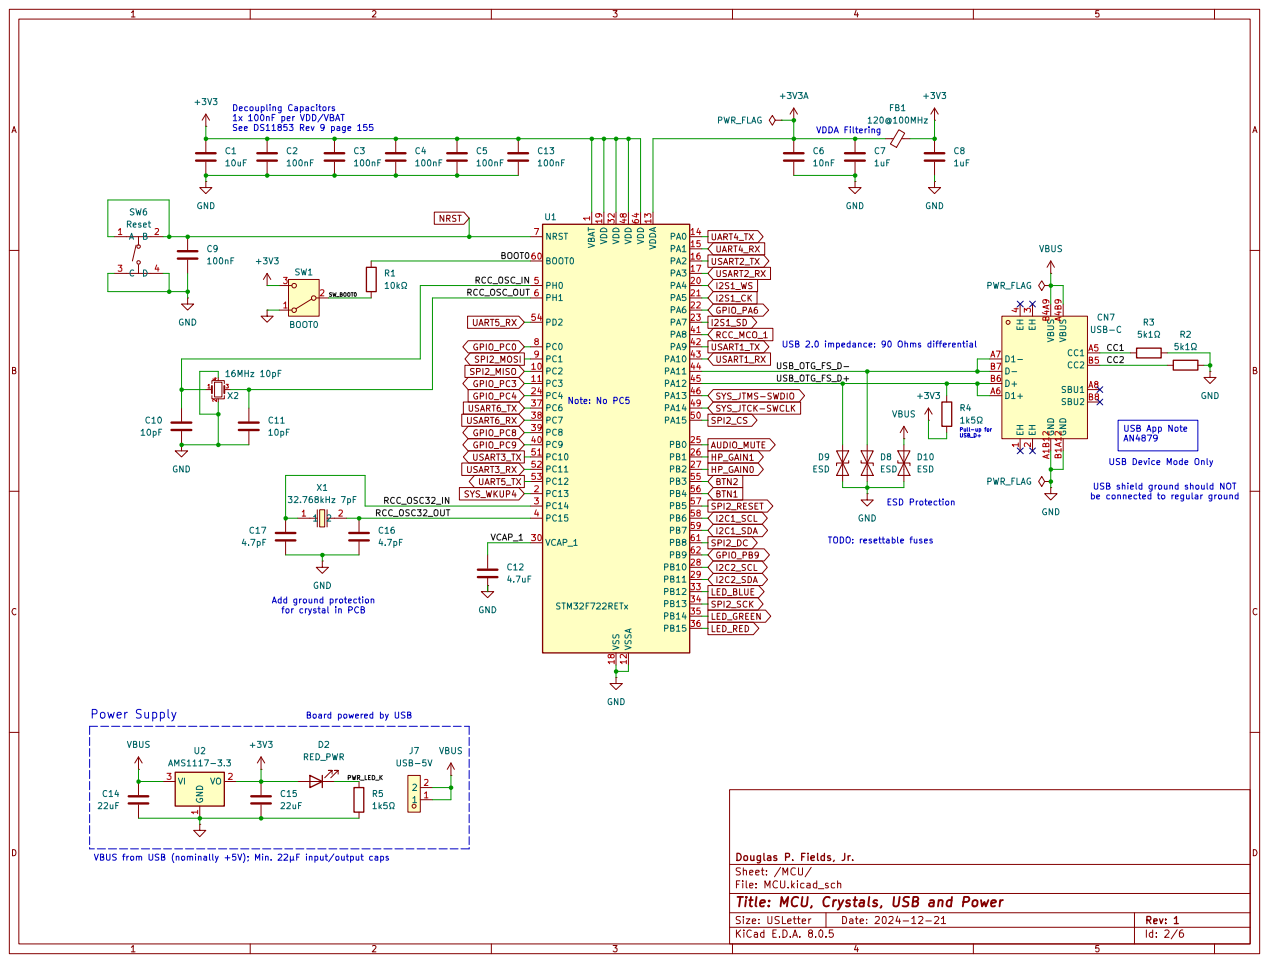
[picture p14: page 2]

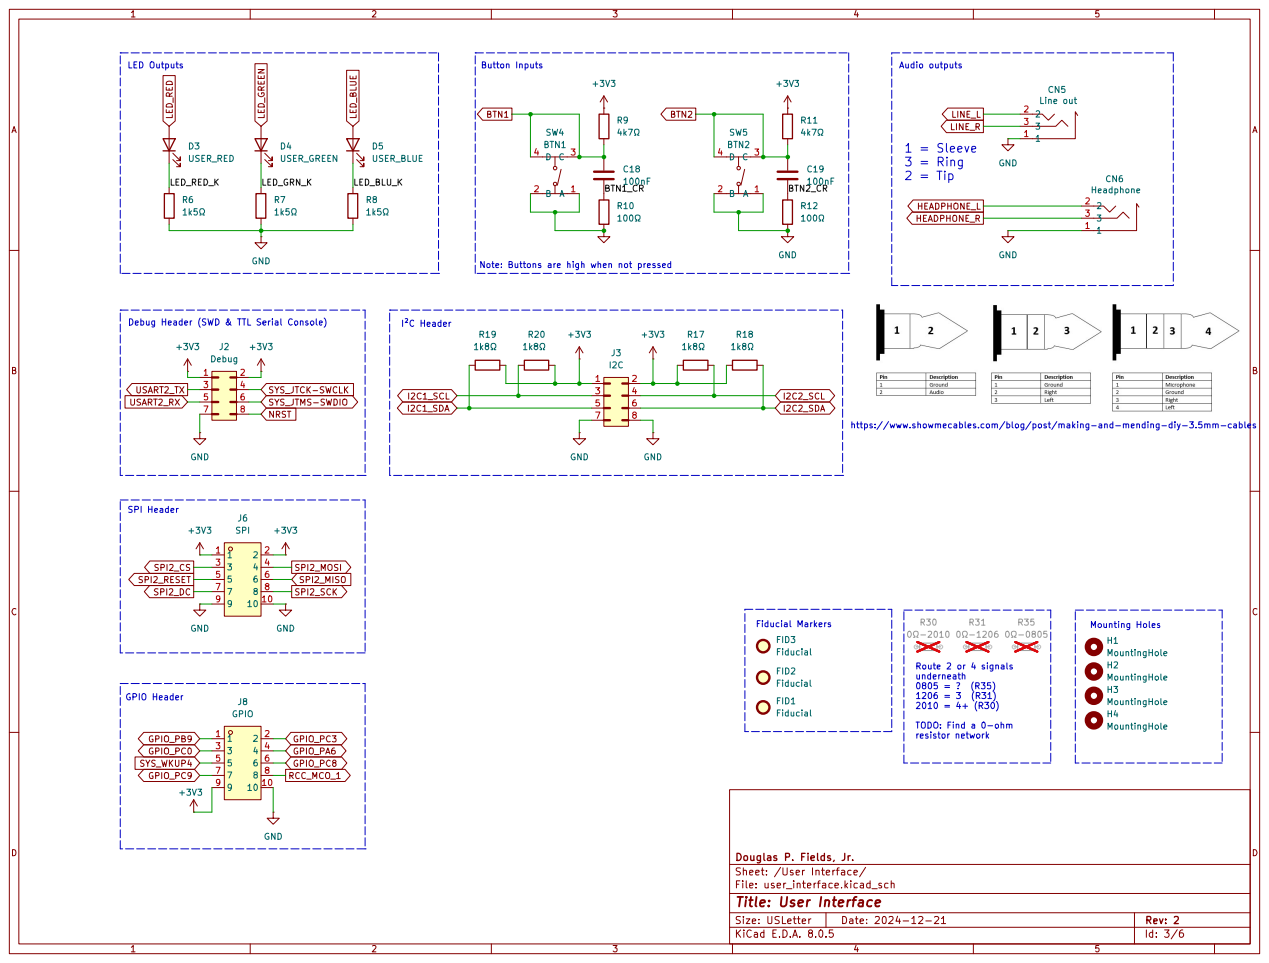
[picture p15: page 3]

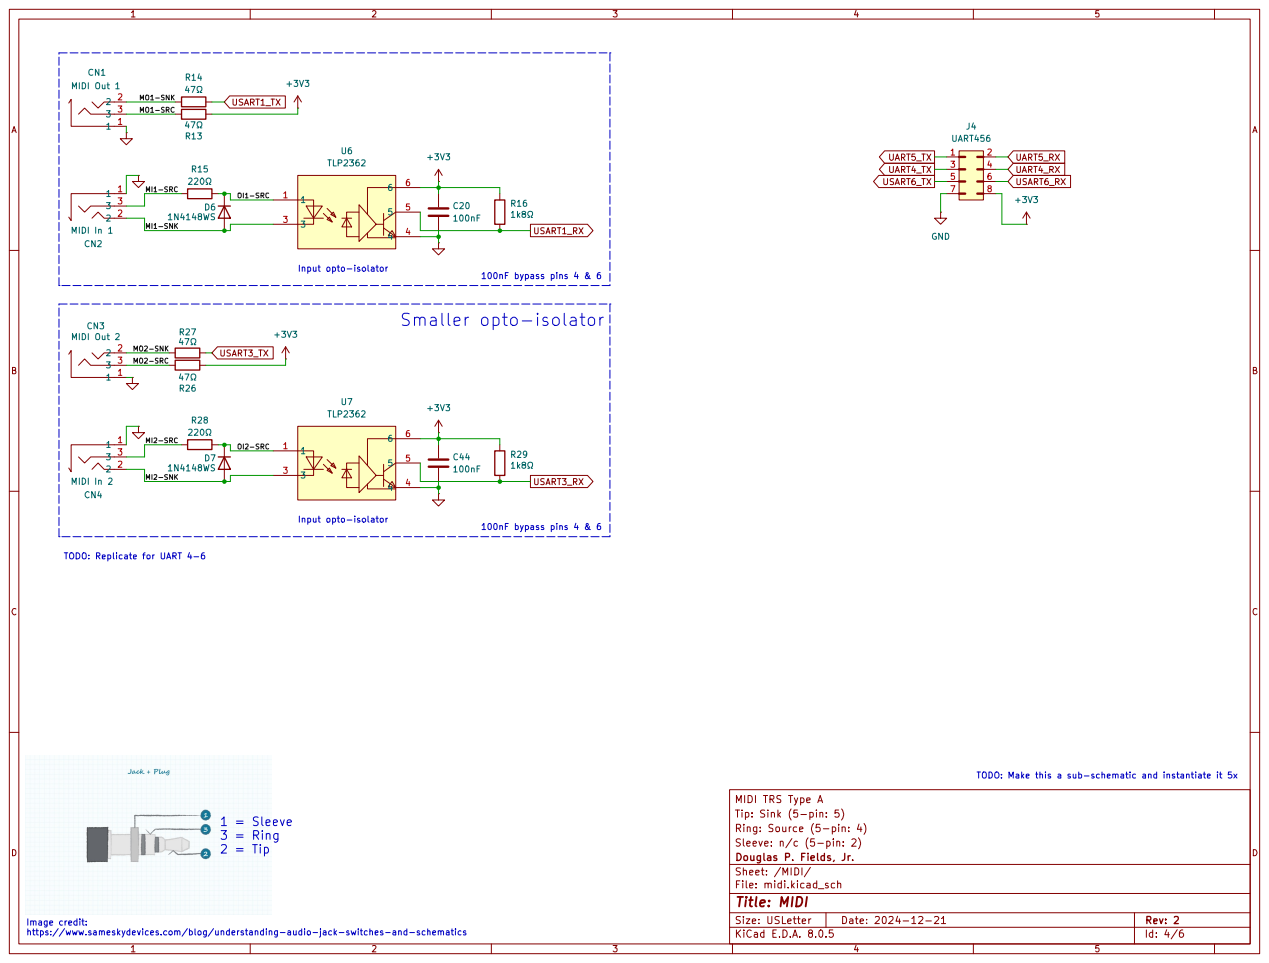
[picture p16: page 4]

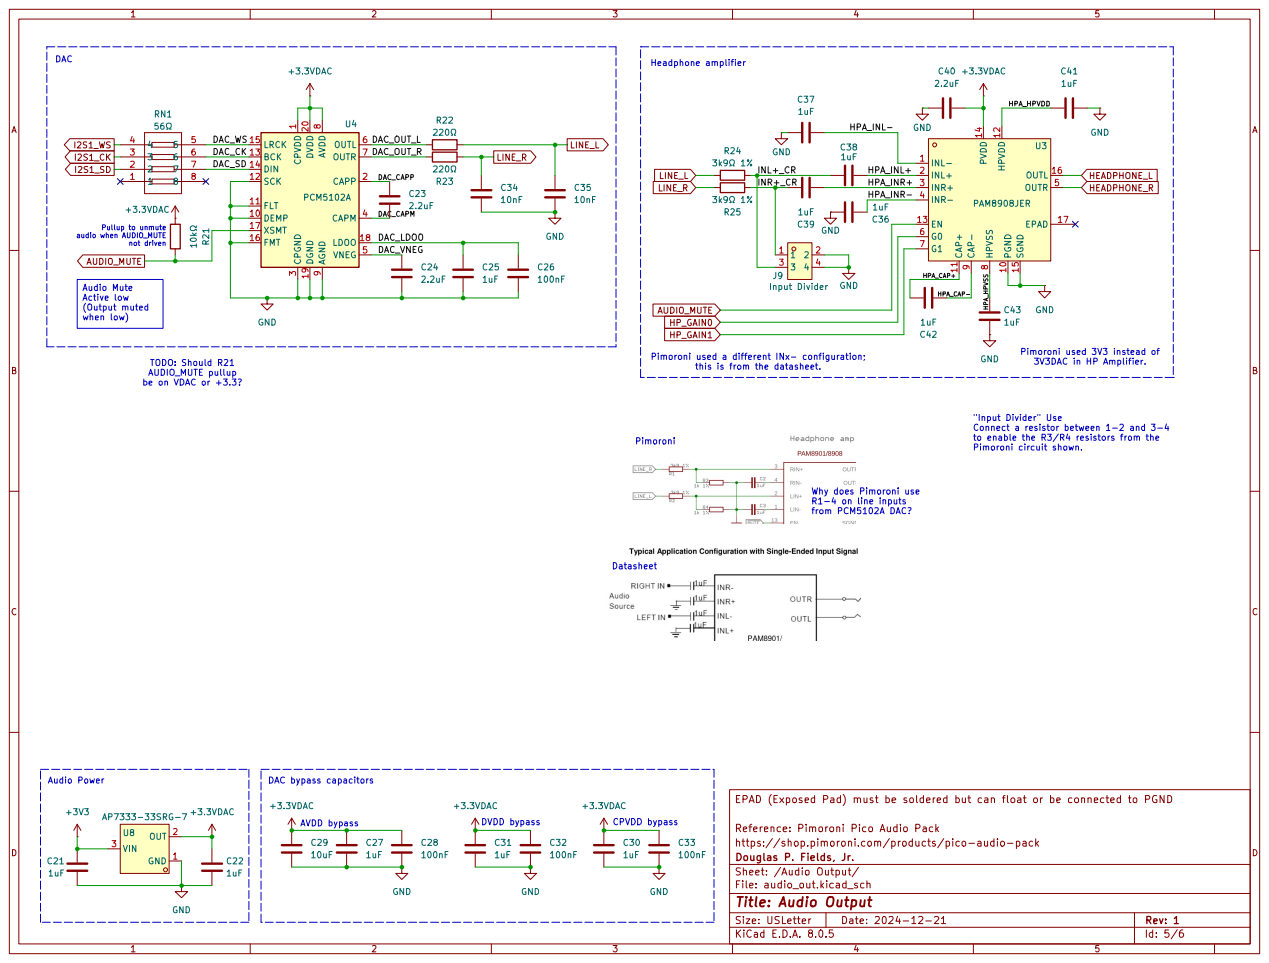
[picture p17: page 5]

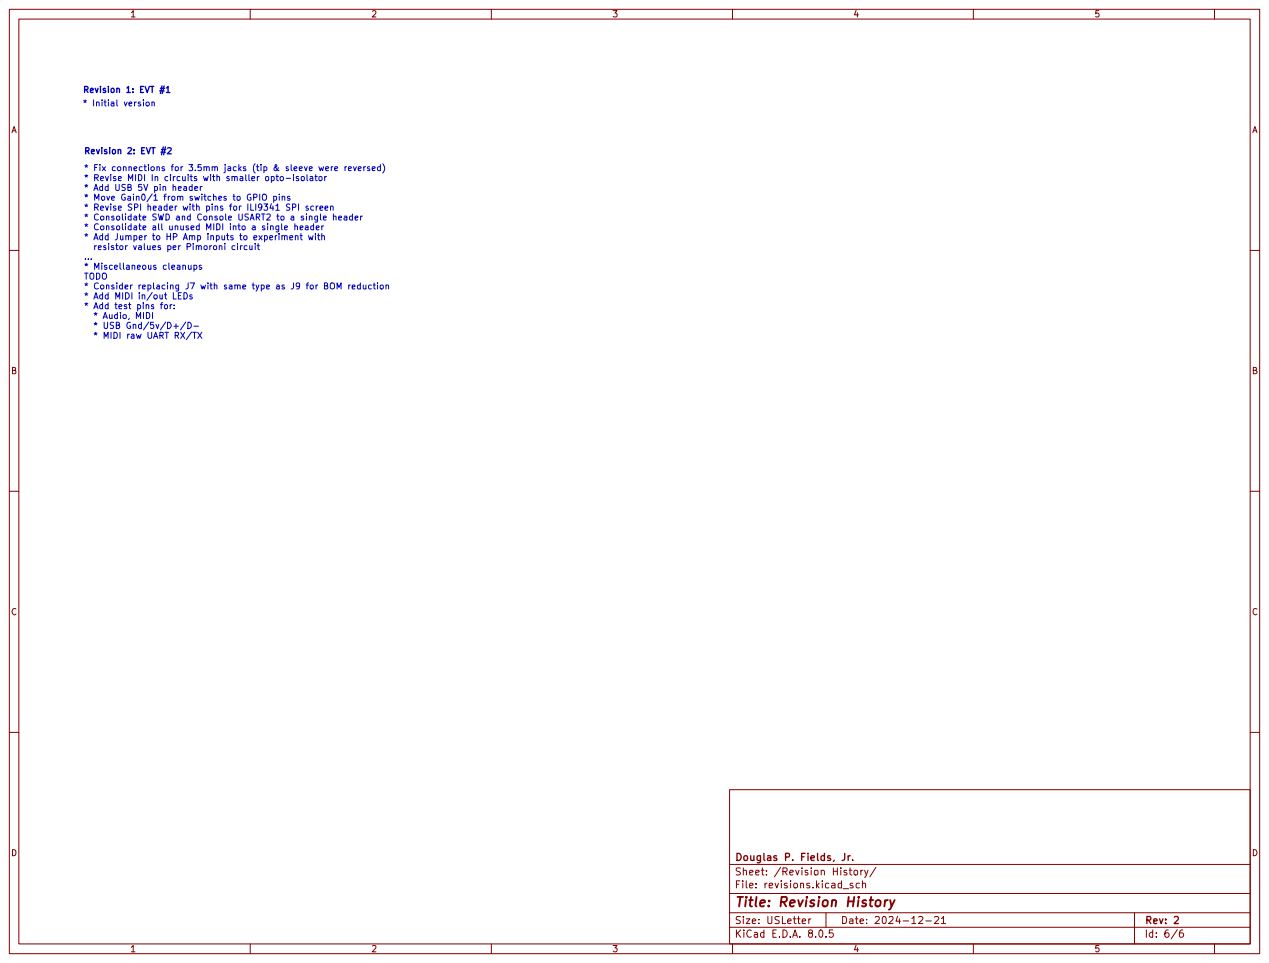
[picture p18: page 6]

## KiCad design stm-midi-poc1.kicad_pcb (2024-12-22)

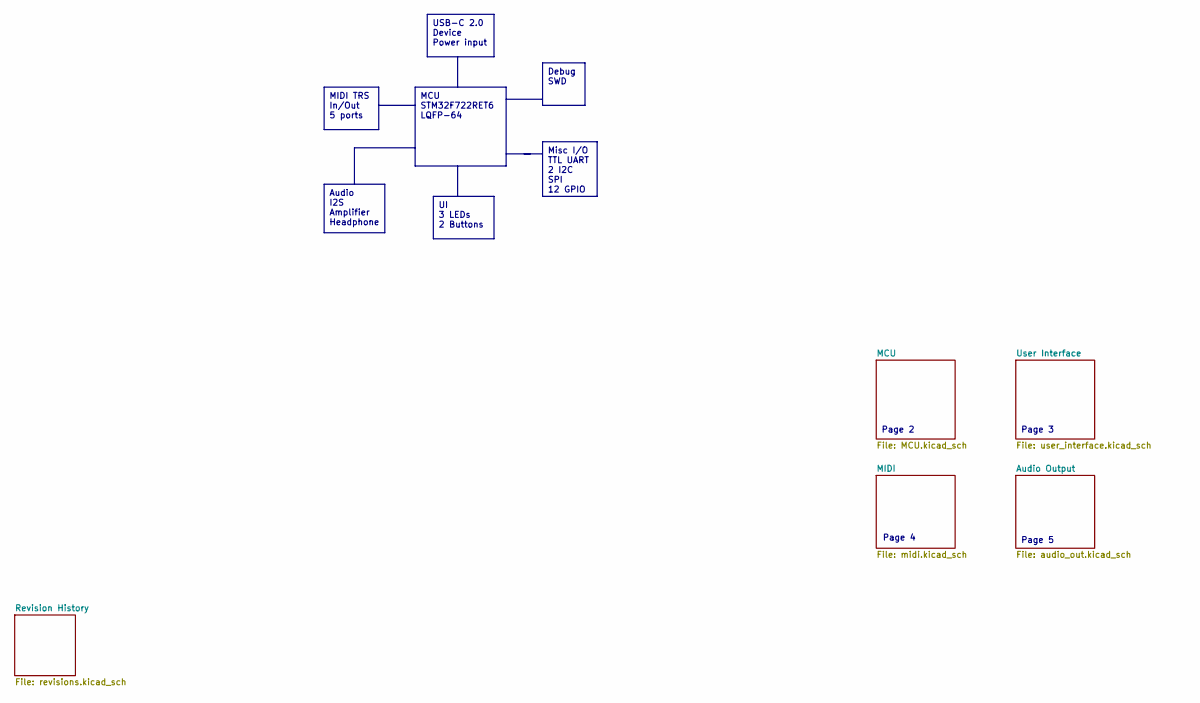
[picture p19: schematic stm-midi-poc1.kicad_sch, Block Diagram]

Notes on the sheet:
MIDI TRS In/Out 5 ports
Misc I/O TTL UART 2 I2C SPI 12 GPIO
MCU STM32F722RET6 LQFP-64
UI 3 LEDs 2 Buttons
USB-C 2.0 Device Power input
Audio I2S Amplifier Headphone
Debug SWD
Page 5
Page 3
Page 2
Page 4

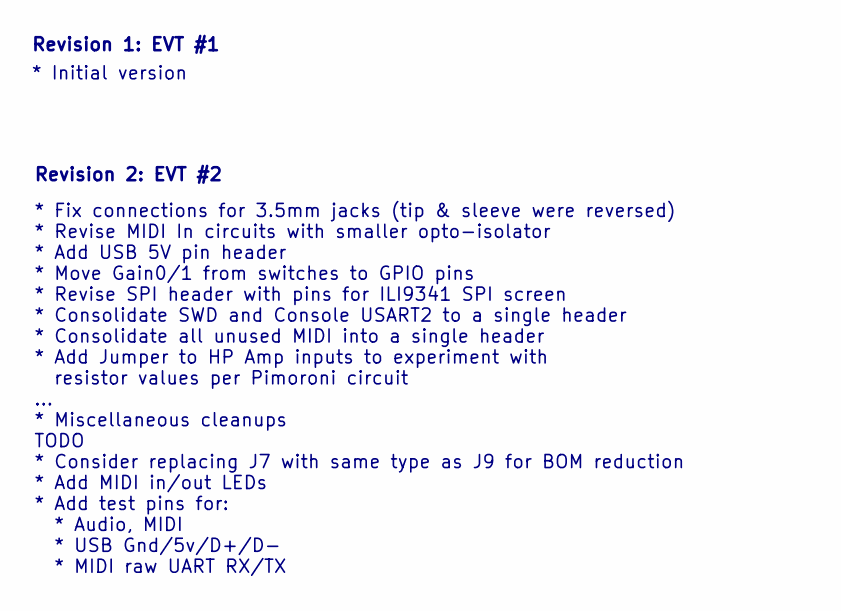
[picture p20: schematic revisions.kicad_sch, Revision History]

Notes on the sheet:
Revision 1: EVT #1
* Fix connections for 3.5mm jacks (tip & sleeve were reversed) * Revise MIDI In circuits with smaller opto-isolator * Add USB 5V pin header * Move Gain0/1 from switches to GPIO pins * Revise SPI header with pins for ILI9341 SPI screen * Consolidate SWD and Console USART2 to a single header * Consol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
Revision 2: EVT #2
* Initial version

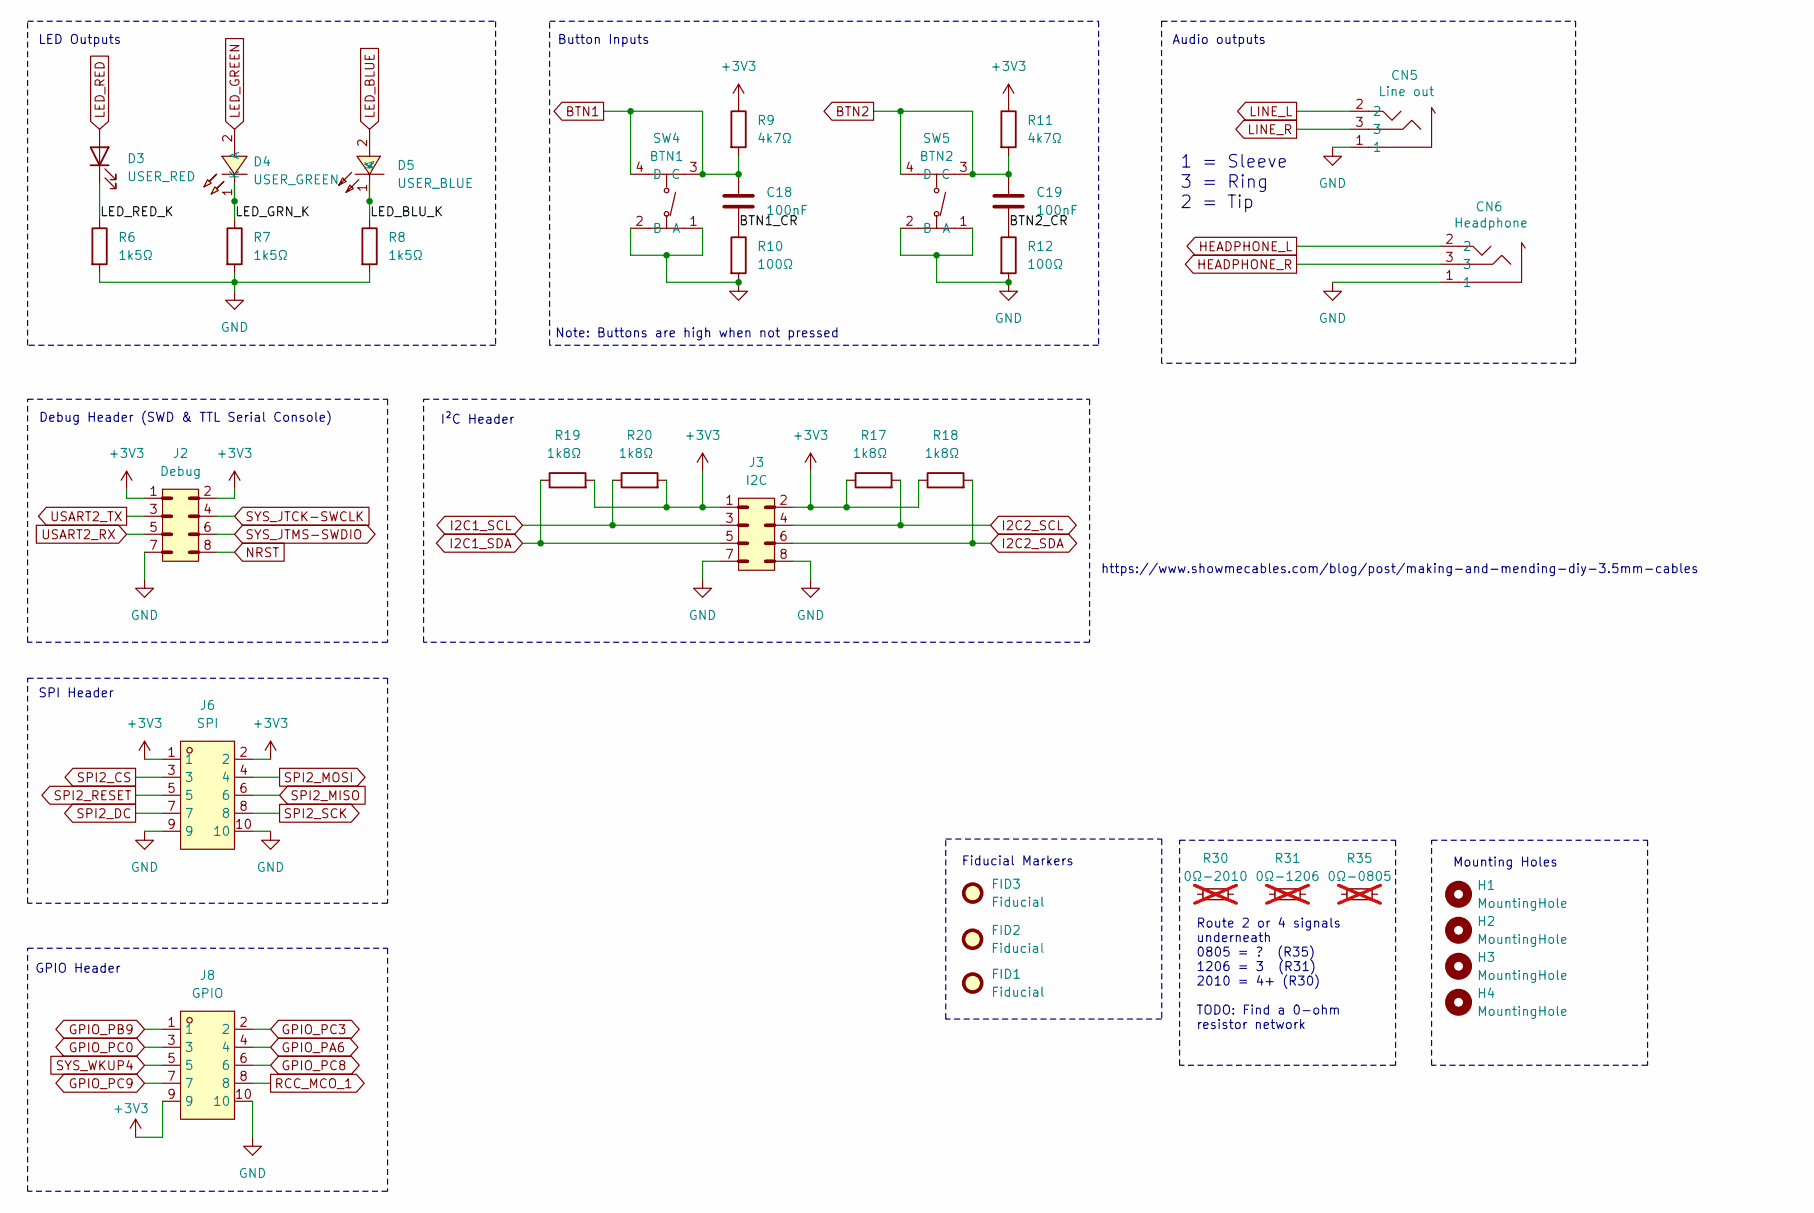
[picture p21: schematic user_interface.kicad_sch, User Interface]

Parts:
C18, C19: 100nF; C_0402_1005Metric; Manu Part CL05B104KB54PNC; LCSC C307331
CN5: Line out; AUDIO-SMD_PJ-321A-4A; Manu Part PJ-321A-4A; LCSC Part C879743
CN6: Headphone; AUDIO-SMD_PJ-321A-4A; Manu Part PJ-321A-4A; LCSC Part C879743
D3: USER_RED; LED_0603_1608Metric; Manu Part KT-0603R; LCSC C2286
D4: USER_GREEN; LED0603-RD; LCSC Part C19189745
D5: USER_BLUE; LED0603-RD; LCSC Part C2288
FID1, FID2, FID3: Fiducial; Fiducial_1mm_Mask2mm
H1, H2, H3, H4: MountingHole; MountingHole_2.2mm_M2
J2: Debug; PinHeader_2x04_P2.54mm_Vertical; Manu Part PZ2.54-2*4; LCSC C5156676
J3: I2C; PinHeader_2x04_P2.54mm_Vertical; Manu Part PZ2.54-2*4; LCSC C5156676
J6: SPI; HDR-TH_10P-P2.54-V-M-R2-C5-S2.54-1; LCSC Part C5156677
J8: GPIO; HDR-TH_10P-P2.54-V-M-R2-C5-S2.54-1; LCSC Part C5156677
R6, R7, R8: 1k5Ω; R_0402_1005Metric; Manu Part 0402WGF1501TCE; LCSC C25867
R9, R11: 4k7Ω; R_0402_1005Metric; Manu Part 0402WGF4701TCE; LCSC C25900
R10, R12: 100Ω; R_0402_1005Metric; Manu Part 0402WGF1000TCE; LCSC C25076
R17, R18, R19, R20: 1k8Ω; R_0402_1005Metric; Manu Part 0402WGF1801TCE; LCSC C25871
R30: 0Ω-2010; R_2010_5025Metric; Manu Part AC2010JK-070RL; LCSC C144433; not fitted
R31: 0Ω-1206; R_1206_3216Metric; Manu Part 1206W4F0000T5E; LCSC C17888; not fitted
R35: 0Ω-0805; R_0805_2012Metric; Manu Part 0805W8F0000T5E; LCSC C17477; not fitted
SW4: BTN1; SW-SMD_4P-L5.1-W5.1-P3.70-LS6.5-TL-2; Manu Part TS-1187A-B-A-B; LCSC Part C318884
SW5: BTN2; SW-SMD_4P-L5.1-W5.1-P3.70-LS6.5-TL-2; Manu Part TS-1187A-B-A-B; LCSC Part C318884

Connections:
+3V3: J2.1, J2.2, J3.1, J3.2, J6.1, J6.2, J8.9, R9.1, R11.1, R17.1, R18.1, R19.2, R20.2; also elsewhere on the board
/User Interface/BTN1_CR: C18.2, R10.1
/User Interface/BTN2_CR: C19.2, R12.1
/User Interface/LED_BLU_K: D5.1 (K), R8.1
/User Interface/LED_GRN_K: D4.1 (K), R7.1
/User Interface/LED_RED_K: D3.1 (K), R6.1
BTN1: C18.1, R9.2, SW4.3 (C), SW4.4 (D); also elsewhere on the board
BTN2: C19.1, R11.2, SW5.3 (C), SW5.4 (D); also elsewhere on the board
GND: CN5.1, CN6.1, J2.7, J3.7, J3.8, J6.9, J6.10, J8.10, R6.2, R7.2, R8.2, R10.2, R12.2, SW4.1 (A), SW4.2 (B), SW5.1 (A), SW5.2 (B); also elsewhere on the board
GPIO_PA6: J8.4; also elsewhere on the board
GPIO_PB9: J8.1; also elsewhere on the board
GPIO_PC0: J8.3; also elsewhere on the board
GPIO_PC3: J8.2; also elsewhere on the board
GPIO_PC8: J8.6; also elsewhere on the board
GPIO_PC9: J8.7; also elsewhere on the board
HEADPHONE_L: CN6.2; also elsewhere on the board
HEADPHONE_R: CN6.3; also elsewhere on the board
I2C1_SCL: J3.3, R20.1; also elsewhere on the board
I2C1_SDA: J3.5, R19.1; also elsewhere on the board
I2C2_SCL: J3.4, R17.2; also elsewhere on the board
I2C2_SDA: J3.6, R18.2; also elsewhere on the board
LED_BLUE: D5.2 (A); also elsewhere on the board
LED_GREEN: D4.2 (A); also elsewhere on the board
LED_RED: D3.2 (A); also elsewhere on the board
LINE_L: CN5.2; also elsewhere on the board
LINE_R: CN5.3; also elsewhere on the board
NRST: J2.8; also elsewhere on the board
RCC_MCO_1: J8.8; also elsewhere on the board
SPI2_CS: J6.3; also elsewhere on the board
SPI2_DC: J6.7; also elsewhere on the board
SPI2_MISO: J6.6; also elsewhere on the board
SPI2_MOSI: J6.4; also elsewhere on the board
SPI2_RESET: J6.5; also elsewhere on the board
SPI2_SCK: J6.8; also elsewhere on the board
SYS_JTCK-SWCLK: J2.4; also elsewhere on the board
SYS_JTMS-SWDIO: J2.6; also elsewhere on the board
SYS_WKUP4: J8.5; also elsewhere on the board
USART2_RX: J2.5; also elsewhere on the board
USART2_TX: J2.3; also elsewhere on the board

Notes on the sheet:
Mounting Holes
SPI Header
Debug Header (SWD & TTL Serial Console)
1 = Sleeve 3 = Ring 2 = Tip
Note: Buttons are high when not pressed
Route 2 or 4 signals underneath 0805 = ? (R35) 1206 = 3 (R31) 2010 = 4+ (R30) TODO: Find a 0-ohm resistor network
Audio outputs
GPIO Header
I²C Header
LED Outputs
https://www.showmecables.com/blog/post/making-and-mending-diy-3.5mm-cables
Button Inputs
Fiducial Markers

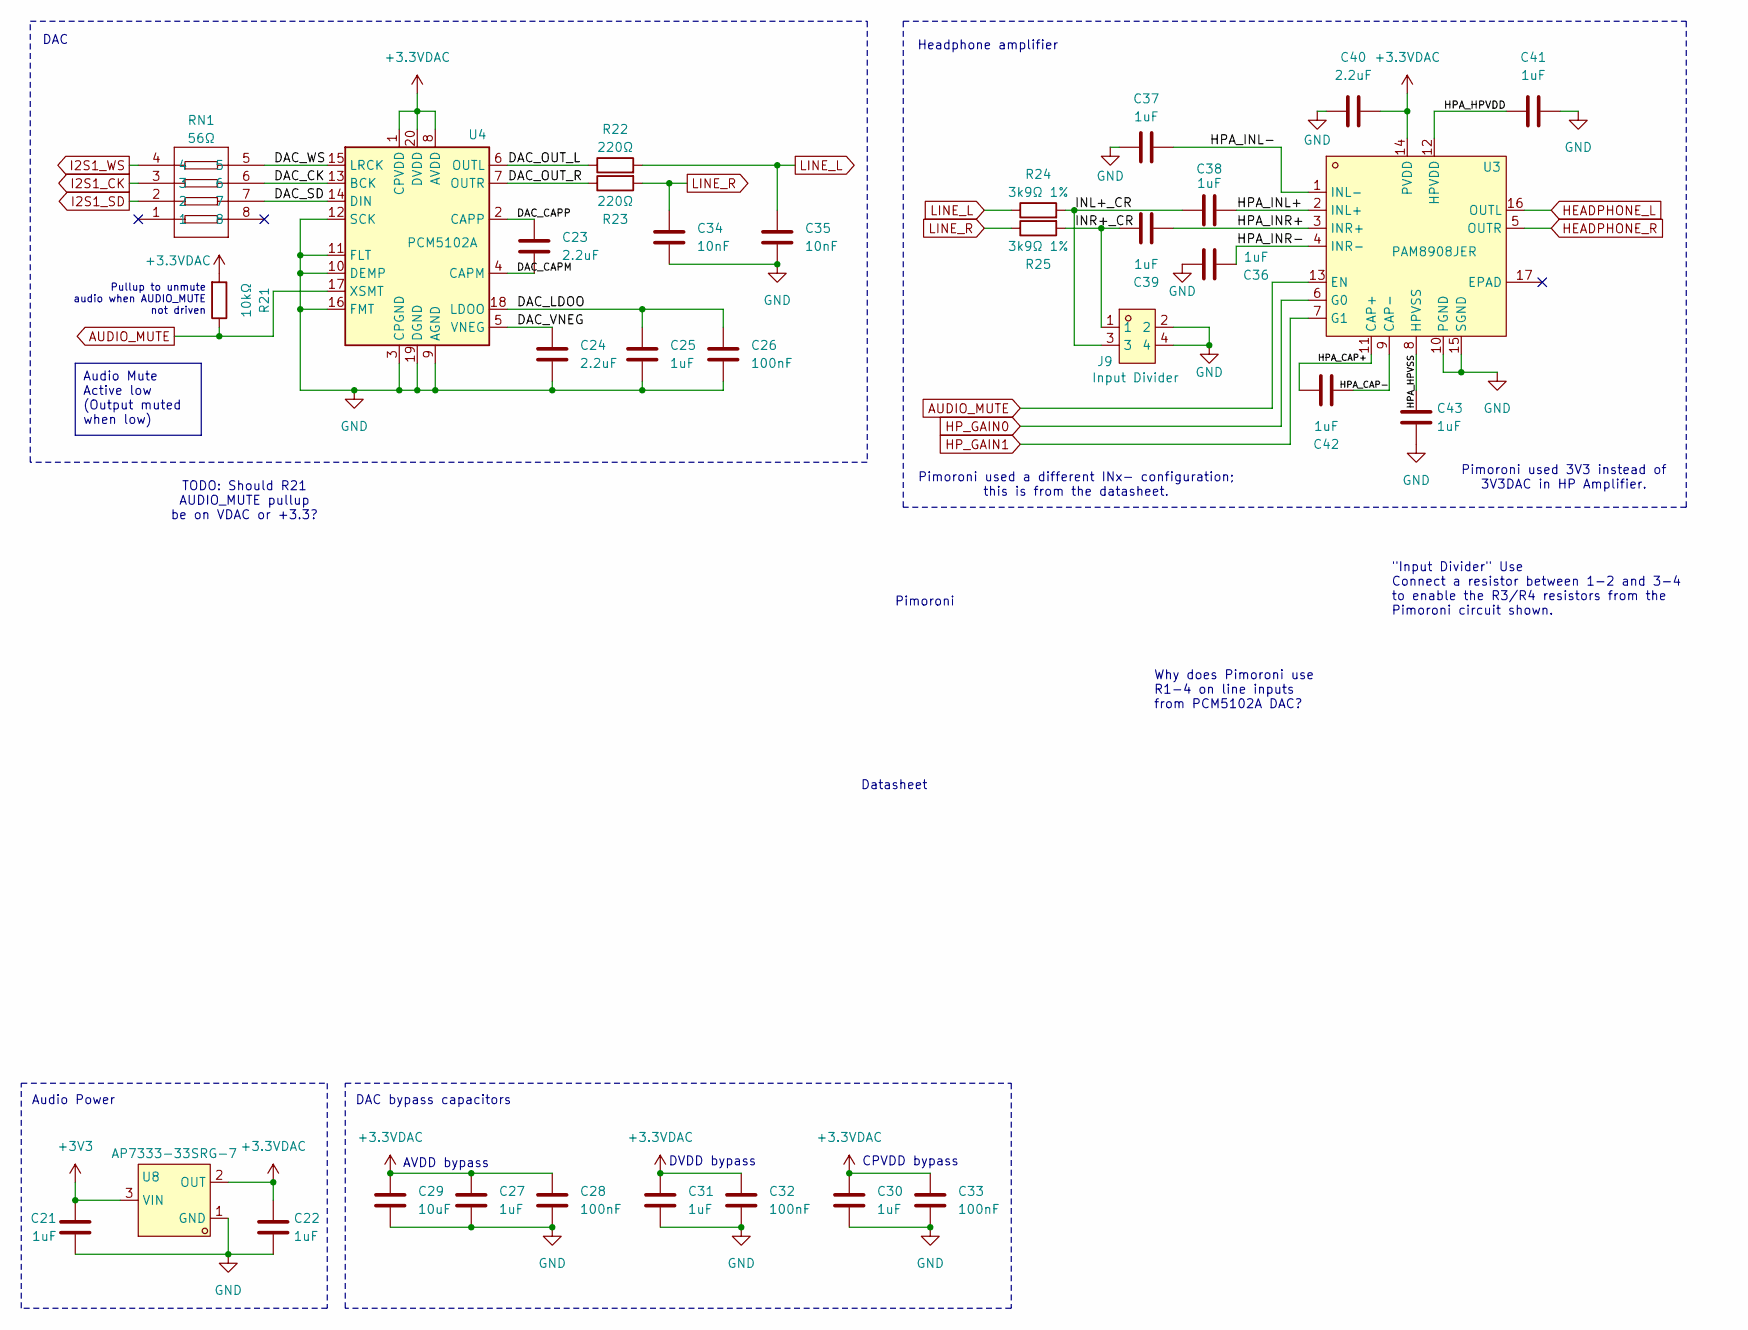
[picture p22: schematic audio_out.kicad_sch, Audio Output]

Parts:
C21, C22, C25, C27, C30, C31, C36, C37, C38, C39, C41, C42, C43: 1uF; C_0402_1005Metric; Manu Part CL05A105KA5NQNC; LCSC C52923
C23, C24, C40: 2.2uF; C_0805_2012Metric; Manu Part CL21A225KBQNNNE; LCSC C377773
C26, C28, C32, C33: 100nF; C_0402_1005Metric; Manu Part CL05B104KB54PNC; LCSC C307331
C29: 10uF; C_0603_1608Metric; Manu Part CL10A106MA8NRNC; LCSC C96446
C34, C35: 10nF; C_0402_1005Metric; Manu Part CL05B103KB5NNNC; LCSC C15195
J9: Input Divider; HDR-TH_4P-P2.54-V-F-R2-C2-S2.54; LCSC Part C2977590
R21: 10kΩ; R_0402_1005Metric; Manu Part 0402WGF1002TCE; LCSC C25744
R22, R23: 220Ω; R_0402_1005Metric; Manu Part 0402WGF2200TCE; LCSC C25091
R24, R25: 3k9Ω 1%; R_0402_1005Metric; Manu Part 0402WGF3901TCE; LCSC C51721
RN1: 56Ω; RES-ARRAY-SMD_0603-8P-L3.2-W1.6-BL; Manu Part 4D03WGJ0560T5E; LCSC Part C25512
U3: PAM8908JER; QFN-16_L3.0-W3.0-P0.50-BL-EP1.7; Manu Part PAM8908JER; LCSC Part C33233
U4: PCM5102A; TSSOP-20_4.4x6.5mm_P0.65mm; Manu Part PCM5102APWR; LCSC C107671
U8: AP7333-33SRG-7; SOT-23-3_L2.9-W1.3-P1.90-LS2.4-BR; Manu Part AP7333-33SRG-7; LCSC Part C150745

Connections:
+3.3VDAC: C22.1, C27.1, C28.1, C29.1, C30.1, C31.1, C32.1, C33.1, C40.2, R21.2, U3.14 (PVDD), U4.1 (CPVDD), U4.8 (AVDD), U4.20 (DVDD), U8.2 (OUT)
+3V3: C21.1, U8.3 (VIN); also elsewhere on the board
/Audio Output/DAC_CAPM: C23.2, U4.4 (CAPM)
/Audio Output/DAC_CAPP: C23.1, U4.2 (CAPP)
/Audio Output/DAC_CK: RN1.6, U4.13 (BCK)
/Audio Output/DAC_LDOO: C25.1, C26.1, U4.18 (LDOO)
/Audio Output/DAC_OUT_L: R22.1, U4.6 (OUTL)
/Audio Output/DAC_OUT_R: R23.1, U4.7 (OUTR)
/Audio Output/DAC_SD: RN1.7, U4.14 (DIN)
/Audio Output/DAC_VNEG: C24.1, U4.5 (VNEG)
/Audio Output/DAC_WS: RN1.5, U4.15 (LRCK)
/Audio Output/HPA_CAP+: C42.2, U3.11 (CAP+)
/Audio Output/HPA_CAP-: C42.1, U3.9 (CAP-)
/Audio Output/HPA_HPVDD: C41.1, U3.12 (HPVDD)
/Audio Output/HPA_HPVSS: C43.1, U3.8 (HPVSS)
/Audio Output/HPA_INL+: C38.2, U3.2 (INL+)
/Audio Output/HPA_INL-: C37.2, U3.1 (INL-)
/Audio Output/HPA_INR+: C39.2, U3.3 (INR+)
/Audio Output/HPA_INR-: C36.2, U3.4 (INR-)
AUDIO_MUTE: R21.1, U3.13 (EN), U4.17 (XSMT); also elsewhere on the board
GND: C21.2, C22.2, C24.2, C25.2, C26.2, C27.2, C28.2, C29.2, C30.2, C31.2, C32.2, C33.2, C34.2, C35.2, C36.1, C37.1, C40.1, C41.2, C43.2, J9.2, J9.4, U3.10 (PGND), U3.15 (SGND), U4.3 (CPGND), U4.9 (AGND), U4.10 (DEMP), U4.11 (FLT), U4.12 (SCK), U4.16 (FMT), U4.19 (DGND), U8.1 (GND); also elsewhere on the board
HEADPHONE_L: U3.16 (OUTL); also elsewhere on the board
HEADPHONE_R: U3.5 (OUTR); also elsewhere on the board
HP_GAIN0: U3.6 (G0); also elsewhere on the board
HP_GAIN1: U3.7 (G1); also elsewhere on the board
I2S1_CK: RN1.3; also elsewhere on the board
I2S1_SD: RN1.2; also elsewhere on the board
I2S1_WS: RN1.4; also elsewhere on the board
LINE_L: C35.1, R22.2, R24.1; also elsewhere on the board
LINE_R: C34.1, R23.2, R25.1; also elsewhere on the board

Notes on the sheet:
Audio Mute Active low (Output muted when low)
Pimoroni used 3V3 instead of 3V3DAC in HP Amplifier.
DVDD bypass
Headphone amplifier
TODO: Should R21 AUDIO_MUTE pullup be on VDAC or +3.3?
Pullup to unmute audio when AUDIO_MUTE not driven
DAC bypass capacitors
CPVDD bypass
Pimoroni
Datasheet
AVDD bypass
Why does Pimoroni use R1-4 on line inputs from PCM5102A DAC?
Audio Power
"Input Divider" Use Connect a resistor between 1-2 and 3-4 to enable the R3/R4 resistors from the Pimoroni circuit shown.
Pimoroni used a different INx- configuration; this is from the datasheet.
DAC

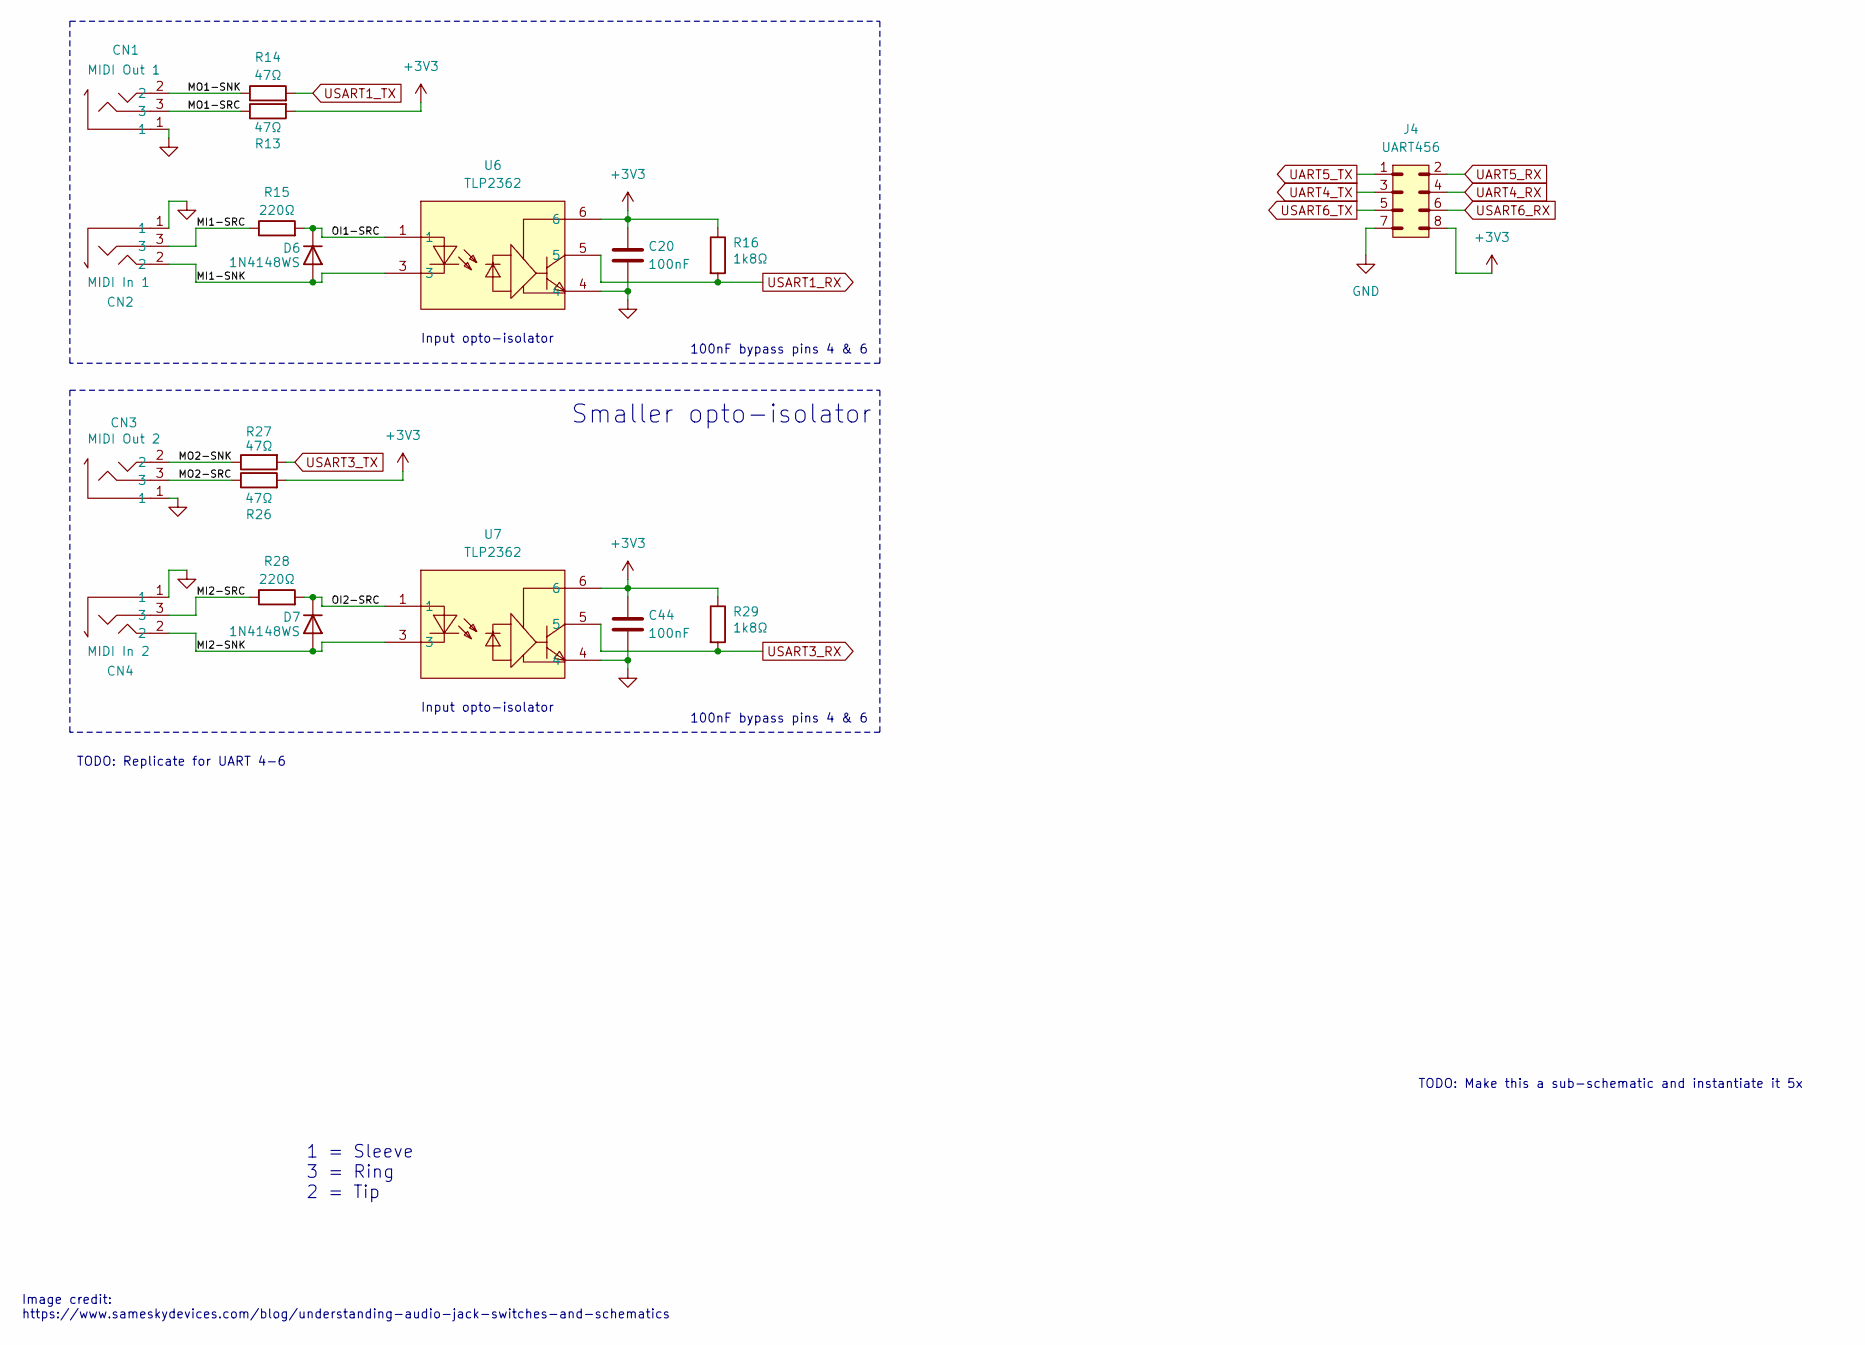
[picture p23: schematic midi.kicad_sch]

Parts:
C20, C44: 100nF; C_0402_1005Metric; Manu Part CL05B104KB54PNC; LCSC C307331
CN1: MIDI Out 1; AUDIO-SMD_PJ-321A-4A; Manu Part PJ-321A-4A; LCSC Part C879743
CN2: MIDI In 1; AUDIO-SMD_PJ-321A-4A; Manu Part PJ-321A-4A; LCSC Part C879743
CN3: MIDI Out 2; AUDIO-SMD_PJ-321A-4A; Manu Part PJ-321A-4A; LCSC Part C879743
CN4: MIDI In 2; AUDIO-SMD_PJ-321A-4A; Manu Part PJ-321A-4A; LCSC Part C879743
D6, D7: 1N4148WS; D_SOD-323; LCSC C2128
J4: UART456; PinHeader_2x04_P2.54mm_Vertical; Manu Part PZ2.54-2*4; LCSC C5156676
R13, R14, R26, R27: 47Ω; R_0402_1005Metric; Manu Part 0402WGF470JTCE; LCSC C25118
R15, R28: 220Ω; R_0402_1005Metric; Manu Part 0402WGF2200TCE; LCSC C25091
R16, R29: 1k8Ω; R_0402_1005Metric; Manu Part 0402WGF1801TCE; LCSC C25871
U6, U7: TLP2362; OPTO-SMD-5_L3.7-W4.6-P1.27-LS7.0-BR; LCSC Part C37658

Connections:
+3V3: C20.1, C44.1, J4.8, R13.2, R16.1, R26.2, R29.1, U6.6, U7.6; also elsewhere on the board
/MIDI/MI1-SNK: CN2.2, D6.2 (A), U6.3
/MIDI/MI1-SRC: CN2.3, R15.1
/MIDI/MI2-SNK: CN4.2, D7.2 (A), U7.3
/MIDI/MI2-SRC: CN4.3, R28.1
/MIDI/MO1-SNK: CN1.2, R14.1
/MIDI/MO1-SRC: CN1.3, R13.1
/MIDI/MO2-SNK: CN3.2, R27.1
/MIDI/MO2-SRC: CN3.3, R26.1
/MIDI/OI1-SRC: D6.1 (K), R15.2, U6.1
/MIDI/OI2-SRC: D7.1 (K), R28.2, U7.1
GND: C20.2, C44.2, CN1.1, CN2.1, CN3.1, CN4.1, J4.7, U6.4, U7.4; also elsewhere on the board
UART4_RX: J4.4; also elsewhere on the board
UART4_TX: J4.3; also elsewhere on the board
UART5_RX: J4.2; also elsewhere on the board
UART5_TX: J4.1; also elsewhere on the board
USART1_RX: R16.2, U6.5; also elsewhere on the board
USART1_TX: R14.2; also elsewhere on the board
USART3_RX: R29.2, U7.5; also elsewhere on the board
USART3_TX: R27.2; also elsewhere on the board
USART6_RX: J4.6; also elsewhere on the board
USART6_TX: J4.5; also elsewhere on the board

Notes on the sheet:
Image credit: https://www.sameskydevices.com/blog/understanding-audio-jack-switches-and-schematics
TODO: Replicate for UART 4-6
Input opto-isolator
1 = Sleeve 3 = Ring 2 = Tip
Smaller opto-isolator
TODO: Make this a sub-schematic and instantiate it 5x
100nF bypass pins 4 & 6

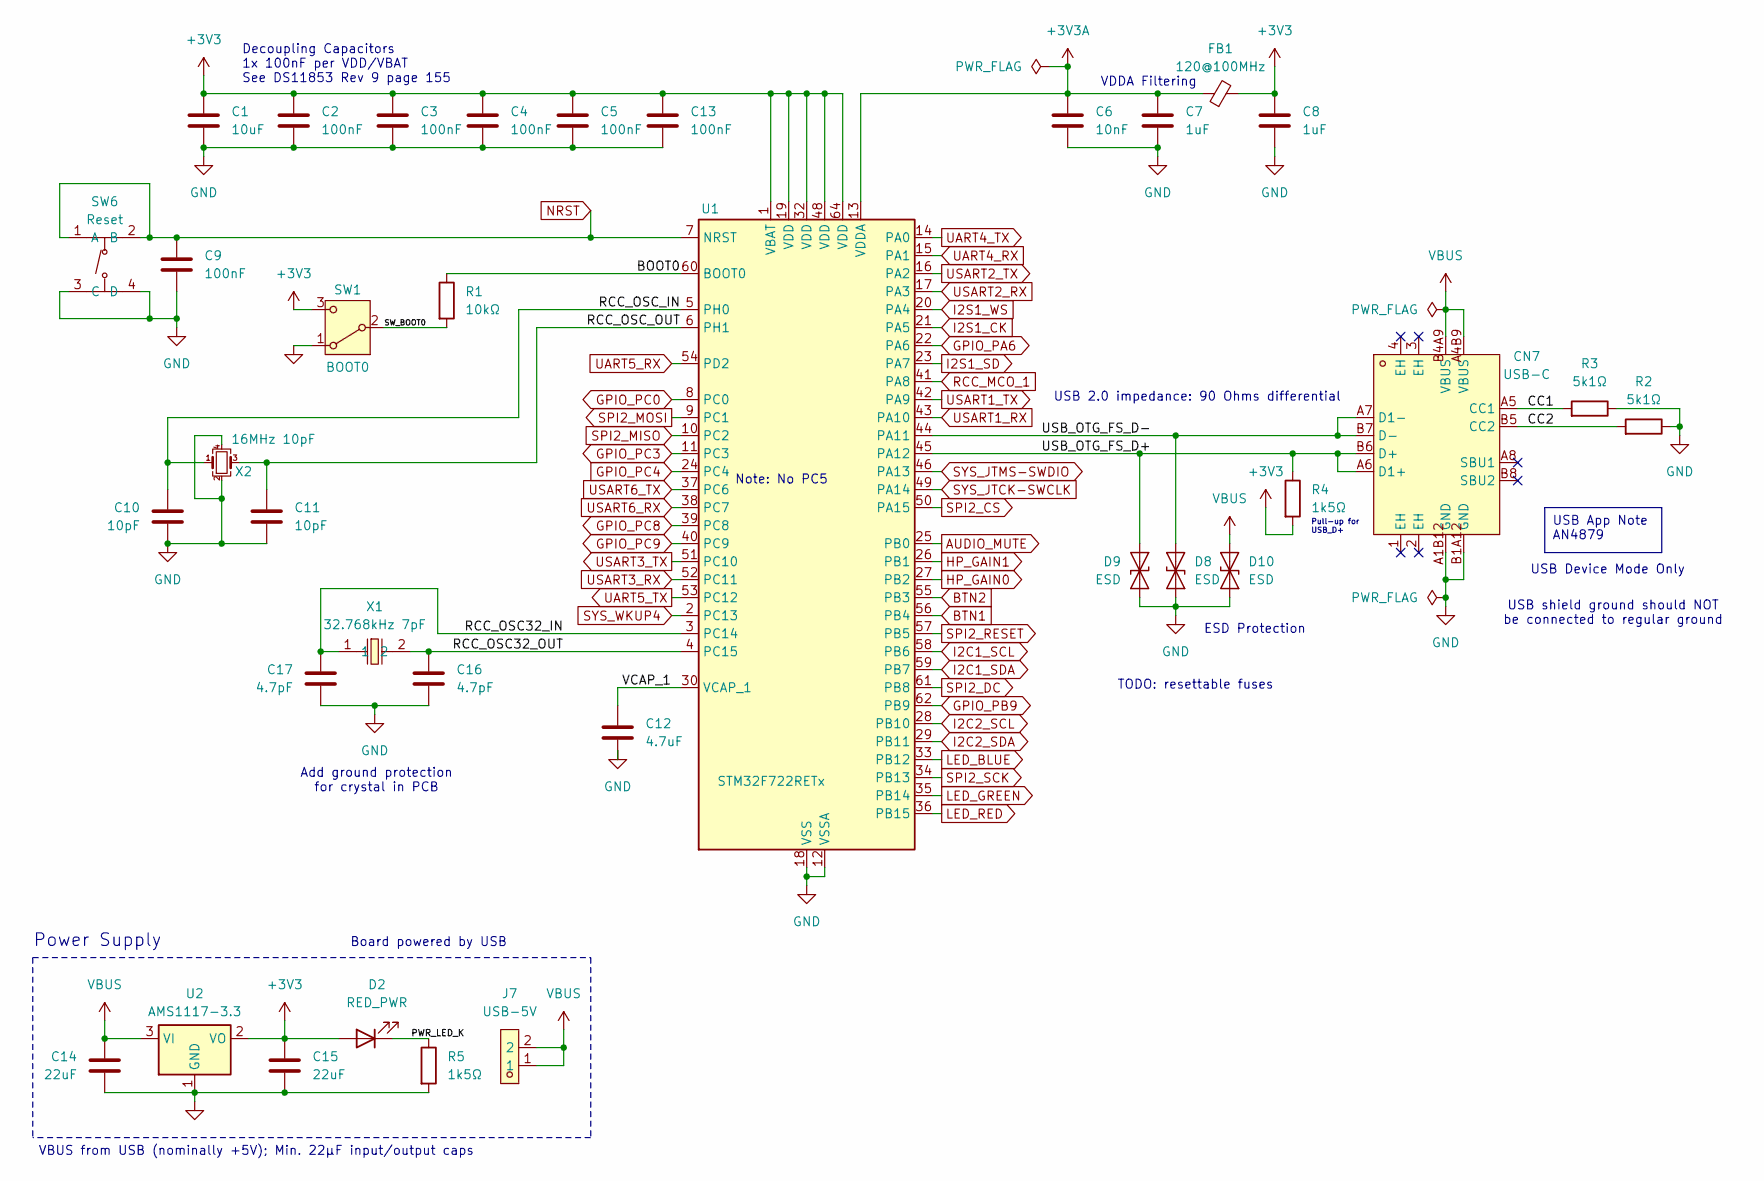
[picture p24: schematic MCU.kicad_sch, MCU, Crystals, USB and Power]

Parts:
C1: 10uF; C_0603_1608Metric; Manu Part CL10A106MA8NRNC; LCSC C96446
C2, C3, C4, C5, C9, C13: 100nF; C_0402_1005Metric; Manu Part CL05B104KB54PNC; LCSC C307331
C6: 10nF; C_0402_1005Metric; Manu Part CL05B103KB5NNNC; LCSC C15195
C7, C8: 1uF; C_0402_1005Metric; Manu Part CL05A105KA5NQNC; LCSC C52923
C10, C11: 10pF; C_0402_1005Metric; Manu Part CL05C100JB5NNNC; LCSC C32949
C12: 4.7uF; C_0603_1608Metric; Manu Part CL10A475KO8NNNC; LCSC C19666
C14, C15: 22uF; C_0805_2012Metric; Manu Part CL21A226MAQNNNE; LCSC C45783
C16, C17: 4.7pF; C_0402_1005Metric; Manu Part 0402CG4R7C500NT; LCSC C1569
CN7: USB-C; USB-C-SMD_GT-USB-7010I; Manu Part GT-USB-7010i; LCSC Part C5362630
D2: RED_PWR; LED_0603_1608Metric; Manu Part KT-0603R; LCSC C2286
D8, D9, D10: ESD; D_SOD-923; Manu Part ESD9B5.0ST5G; LCSC C111566
FB1: 120@100MHz; L_0603_1608Metric; Manu Part FCM1608KF-601T05; LCSC C133937
J7: USB-5V; HDR-TH_2P-P2.54-V-M-1; LCSC Part C5383111
R1: 10kΩ; R_0402_1005Metric; Manu Part 0402WGF1002TCE; LCSC C25744
R2, R3: 5k1Ω; R_0402_1005Metric; Manu Part 0402WGF5101TCE; LCSC C25905
R4, R5: 1k5Ω; R_0402_1005Metric; Manu Part 0402WGF1501TCE; LCSC C25867
SW1: BOOT0; SW_SPDT_PCM12; Manu Part SSSS811101; LCSC C109335
SW6: Reset; SW-SMD_4P-L5.1-W5.1-P3.70-LS6.5-TL-2; Manu Part TS-1187A-B-A-B; LCSC Part C318884
U1: STM32F722RETx; LQFP-64_10x10mm_P0.5mm; Manu Part STM32F722RET6; LCSC C118207
U2: AMS1117-3.3; SOT-223-3_TabPin2; Manu Part AMS1117-3.3; LCSC C6186
X1: 32.768kHz 7pF; FC-135R_L3.2-W1.5; Manu Part Q13FC13500002; LCSC Part C48615
X2: 16MHz 10pF; Crystal_SMD_3225-4Pin_3.2x2.5mm; Manu Part X322516MMB4SI; LCSC C112972

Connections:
+3V3: C1.1, C2.1, C3.1, C4.1, C5.1, C8.1, C13.1, C15.1, D2.2 (A), FB1.2, R4.2, SW1.3 (C), U1.1 (VBAT), U1.19 (VDD), U1.32 (VDD), U1.48 (VDD), U1.64 (VDD), U2.2 (VO); also elsewhere on the board
+3V3A: C6.1, C7.1, FB1.1, U1.13 (VDDA)
/MCU/BOOT0: R1.1, U1.60 (BOOT0)
/MCU/CC1: CN7.A5 (CC1), R3.2
/MCU/CC2: CN7.B5 (CC2), R2.2
/MCU/PWR_LED_K: D2.1 (K), R5.1
/MCU/RCC_OSC32_IN: C17.1, U1.3 (PC14), X1.1
/MCU/RCC_OSC32_OUT: C16.1, U1.4 (PC15), X1.2
/MCU/RCC_OSC_IN: C10.1, U1.5 (PH0), X2.1
/MCU/RCC_OSC_OUT: C11.1, U1.6 (PH1), X2.3
/MCU/SW_BOOT0: R1.2, SW1.2 (B)
/MCU/USB_OTG_FS_D+: CN7.A6 (D1+), CN7.B6 (D+), D9.2 (A2), R4.1, U1.45 (PA12)
/MCU/USB_OTG_FS_D-: CN7.A7 (D1-), CN7.B7 (D-), D8.2 (A2), U1.44 (PA11)
/MCU/VCAP_1: C12.1, U1.30 (VCAP_1)
AUDIO_MUTE: U1.25 (PB0); also elsewhere on the board
BTN1: U1.56 (PB4); also elsewhere on the board
BTN2: U1.55 (PB3); also elsewhere on the board
GND: C1.2, C2.2, C3.2, C4.2, C5.2, C6.2, C7.2, C8.2, C9.2, C10.2, C11.2, C12.2, C13.2, C14.2, C15.2, C16.2, C17.2, CN7.A1B12 (GND), CN7.B1A12 (GND), D8.1 (A1), D9.1 (A1), D10.1 (A1), R2.1, R3.1, R5.2, SW1.1 (A), SW6.3 (C), SW6.4 (D), U1.12 (VSSA), U1.18 (VSS), U1.31 (VSS), U1.47 (VSS), U1.63 (VSS), U2.1 (GND), X2.2, X2.4; also elsewhere on the board
GPIO_PA6: U1.22 (PA6); also elsewhere on the board
GPIO_PB9: U1.62 (PB9); also elsewhere on the board
GPIO_PC0: U1.8 (PC0); also elsewhere on the board
GPIO_PC3: U1.11 (PC3); also elsewhere on the board
GPIO_PC4: U1.24 (PC4)
GPIO_PC8: U1.39 (PC8); also elsewhere on the board
GPIO_PC9: U1.40 (PC9); also elsewhere on the board
HP_GAIN0: U1.27 (PB2); also elsewhere on the board
HP_GAIN1: U1.26 (PB1); also elsewhere on the board
I2C1_SCL: U1.58 (PB6); also elsewhere on the board
I2C1_SDA: U1.59 (PB7); also elsewhere on the board
I2C2_SCL: U1.28 (PB10); also elsewhere on the board
I2C2_SDA: U1.29 (PB11); also elsewhere on the board
I2S1_CK: U1.21 (PA5); also elsewhere on the board
I2S1_SD: U1.23 (PA7); also elsewhere on the board
I2S1_WS: U1.20 (PA4); also elsewhere on the board
LED_BLUE: U1.33 (PB12); also elsewhere on the board
LED_GREEN: U1.35 (PB14); also elsewhere on the board
LED_RED: U1.36 (PB15); also elsewhere on the board
NRST: C9.1, SW6.1 (A), SW6.2 (B), U1.7 (NRST); also elsewhere on the board
RCC_MCO_1: U1.41 (PA8); also elsewhere on the board
SPI2_CS: U1.50 (PA15); also elsewhere on the board
SPI2_DC: U1.61 (PB8); also elsewhere on the board
SPI2_MISO: U1.10 (PC2); also elsewhere on the board
SPI2_MOSI: U1.9 (PC1); also elsewhere on the board
SPI2_RESET: U1.57 (PB5); also elsewhere on the board
SPI2_SCK: U1.34 (PB13); also elsewhere on the board
SYS_JTCK-SWCLK: U1.49 (PA14); also elsewhere on the board
SYS_JTMS-SWDIO: U1.46 (PA13); also elsewhere on the board
SYS_WKUP4: U1.2 (PC13); also elsewhere on the board
UART4_RX: U1.15 (PA1); also elsewhere on the board
UART4_TX: U1.14 (PA0); also elsewhere on the board
UART5_RX: U1.54 (PD2); also elsewhere on the board
UART5_TX: U1.53 (PC12); also elsewhere on the board
USART1_RX: U1.43 (PA10); also elsewhere on the board
USART1_TX: U1.42 (PA9); also elsewhere on the board
USART2_RX: U1.17 (PA3); also elsewhere on the board
USART2_TX: U1.16 (PA2); also elsewhere on the board
USART3_RX: U1.52 (PC11); also elsewhere on the board
USART3_TX: U1.51 (PC10); also elsewhere on the board
USART6_RX: U1.38 (PC7); also elsewhere on the board
USART6_TX: U1.37 (PC6); also elsewhere on the board
VBUS: C14.1, CN7.A4B9 (VBUS), CN7.B4A9 (VBUS), D10.2 (A2), J7.1, J7.2, U2.3 (VI)

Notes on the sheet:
USB App Note AN4879
Decoupling Capacitors 1x 100nF per VDD/VBAT See DS11853 Rev 9 page 155
Pull-up for USB_D+
Board powered by USB
Add ground protection for crystal in PCB
USB Device Mode Only
USB 2.0 impedance: 90 Ohms differential
Power Supply
ESD Protection
TODO: resettable fuses
VBUS from USB (nominally +5V); Min. 22μF input/output caps
VDDA Filtering
Note: No PC5
USB shield ground should NOT be connected to regular ground

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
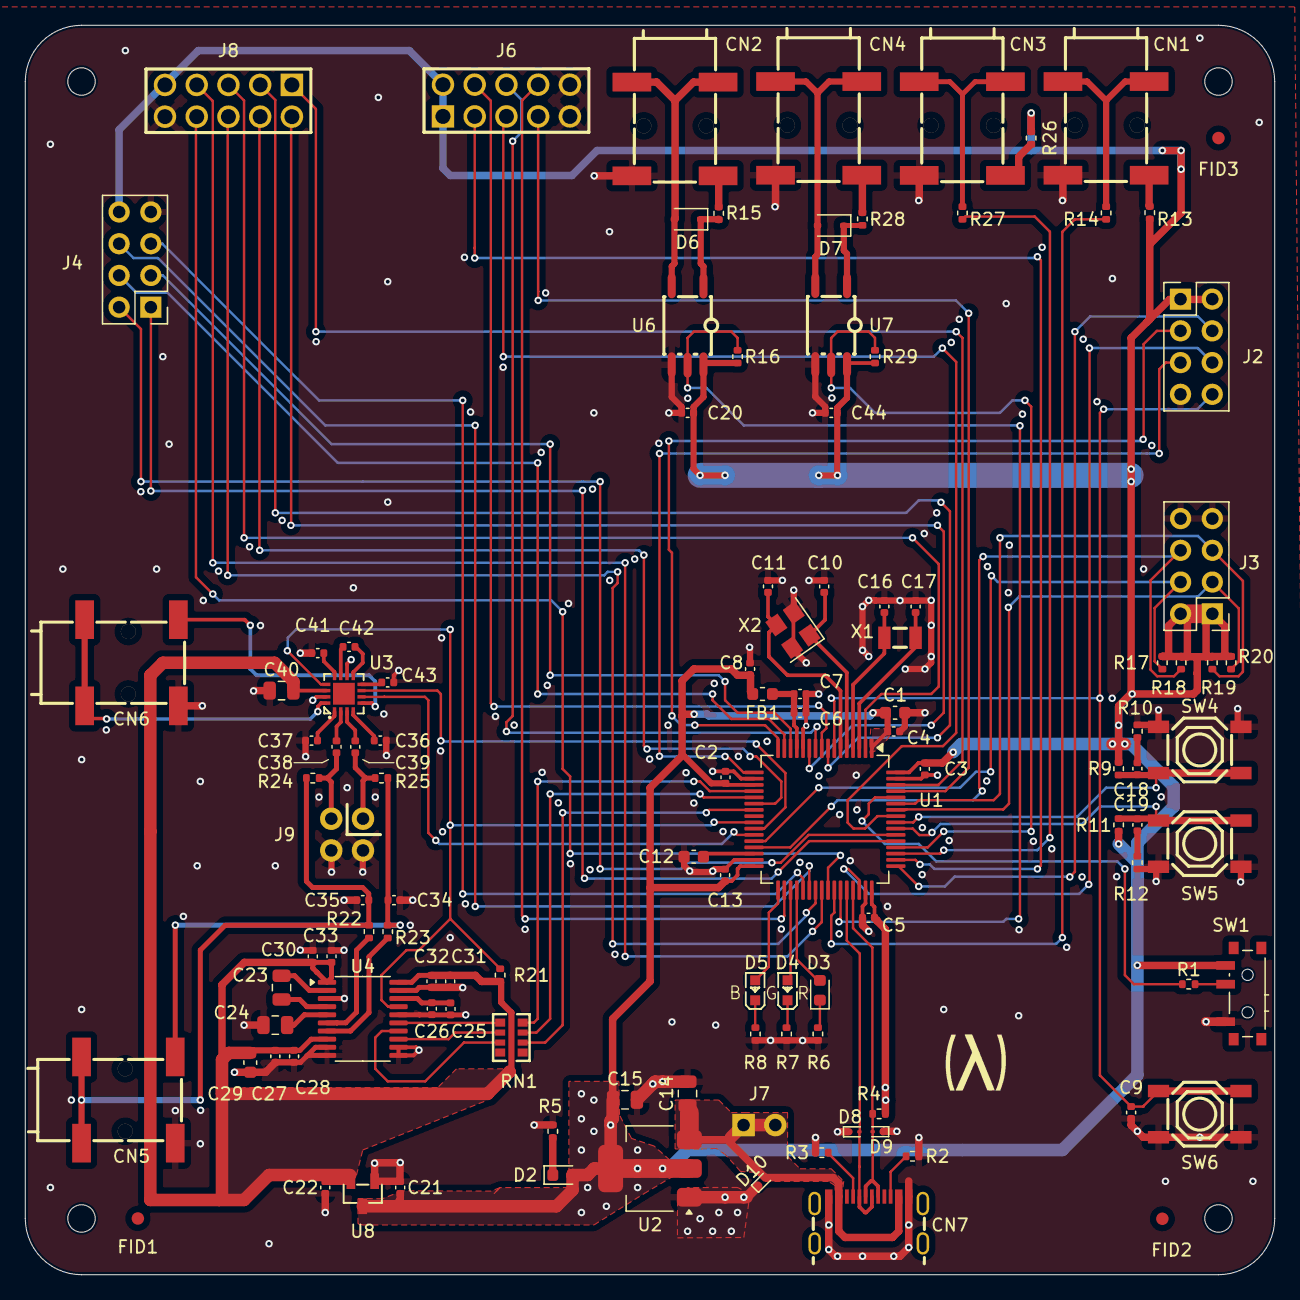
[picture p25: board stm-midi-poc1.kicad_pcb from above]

Board: 4 copper layers, 100.0 x 100.0 mm, 118 parts (0 on the bottom side), 99 nets.

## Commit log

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2024-10-06 Updated schematic with parts found in JLCPCB parts database. Updated footprints, 3d models for those items. All schematic symbols now have LCSC part numbers, footprints and 3D models. No PCB layout h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
    [6N137S-TA1.stp, AUDIO_TH_PJ-3210-4A.pcbdoc, MCU.kicad_sch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]
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2024-10-06 Move related PCB components near each other in preparation of PCB layout.
    [midi.kicad_sch, stm-midi-poc1.kicad_pcb]
2024-10-07 Group PCB components together more. Replace 2x2x4 by 1x2x8 connector.
    [MCU.kicad_sch, audio_out.kicad_sch, midi.kicad_sch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]
2024-10-12 Create PCB outline and move components into better locations. (Not done yet!) Update schematic a little bit with additional nets and clarifications. Add mounting holes. Unify components/footprints.
    [MCU.kicad_sch, midi.kicad_sch, stm-midi-poc1.kicad_pcb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]
2024-10-12 Ready to start routing the PCB I think
    [audio_out.kicad_sch, stm-midi-poc1.kicad_pcb]
2024-10-12 Connected all power for Decoupling Caps
    [MCU.kicad_sch, stm-midi-poc1.kicad_pcb]
2024-10-12 Connected the two crystals
    [audio_out.kicad_sch, stm-midi-poc1.kicad_pcb]
2024-10-12 Work on power section and some miscellaneous small areas
    [stm-midi-poc1.kicad_pcb, user_interface.kicad_sch]
2024-10-12 Routed USB data lines; revised USB ESD for 2-layer board.
    [MCU.kicad_sch, stm-midi-poc1.kicad_pcb]
2024-10-12 Modify power to analog side.
    [stm-midi-poc1.kicad_pcb, user_interface.kicad_sch]
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2024-10-14 Routed the SWD. I don't think it will be possible to do this on a 2-layer board anymore. I already had to use several 0-ohm resistors.
    [MCU.kicad_sch, stm-midi-poc1.kicad_pcb, user_interface.kicad_sch]
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2024-10-14 Updates to clear DRC checker errors.
    [stm-midi-poc1.kicad_pcb]
2024-10-14 Move to 4 layer board; no other changes. S/G/S/G Top to Bottom.
    [stm-midi-poc1.kicad_pcb]
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2024-10-14 Amateur hour. Routed all power and SPI, I2C, MIDI. Left GPIO and UARTs undone. Probably need to restart from scratch.
    [stm-midi-poc1.kicad_pcb]
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2024-10-19 Removed all vias/tracks and moved signal layers to outside for this EVT board design
    [stm-midi-poc1.kicad_pcb]
2024-10-19 Routed all decoupling caps on top layer, as well as USB power input.
    [stm-midi-poc1.kicad_pcb]
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2024-10-20 Added GND routing for DAC, USB, power areas
    [stm-midi-poc1.kicad_pcb]
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2024-10-20 Routed I²C (previous commit was WIP for I²C as well)
    [stm-midi-poc1.kicad_pcb]
2024-10-20 Routed Reset & Boot0
    [stm-midi-poc1.kicad_pcb]
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2024-10-20 Routed UART4 - may need to be changed for its pinout
    [stm-midi-poc1.kicad_pcb]
2024-10-25 All signals now routed through revised GPIO pinout. TODO: Put ground vias everywhere needed for signal vias.
    [midi.kicad_sch, stm-midi-poc1.kicad_pcb, user_interface.kicad_sch]
2024-10-25 All power now routed. TODO: Fix all DRC warnings
    [audio_out.kicad_sch, stm-midi-poc1.kicad_pcb]
2024-10-25 All PCB DRC rule errors fixed.
    [stm-midi-poc1.kicad_pcb]
2024-10-25 All important DRC warnings addressed. Others ignored. Check against Schematic complete.
    [stm-midi-poc1.kicad_pcb]
2024-10-25 Rotate all silkscreen up. Move all silkscreen off vias. Misc cleanups.
    [stm-midi-poc1.kicad_pcb]
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2024-10-25 Added ground fill to both signal layers, including vias where empty islands formed.
    [stm-midi-poc1.kicad_pcb]
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2024-10-25 Added logo silk screen/footprint, exported some files (not final)
    [bom.csv, designators.csv, positions.csv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]
2024-10-26 1. Update README with info on my KiCAD component library. 2. Add Fiducial markers. 3. Add LCSC IDs for all parts in BOM.
    [MCU.kicad_sch, audio_out.kicad_sch, midi.kicad_sch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]
2024-10-26 1. Remove unused components on schematic. 2. Find other color LEDs in JLCPCB.
    [MCU.kicad_sch, audio_out.kicad_sch, midi.kicad_sch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]
2024-10-26 Found an in-stock blue LED but it is expensive.
    [BOM-stm-midi-poc1.csv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]
2024-10-26 Trying to get things ready for sending to JLCPCB
    [BOM-stm-midi-poc1.csv, bom.csv, designators.csv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]
2024-10-27 Reviewing every item in the BOM against LCSC database. Found several errors already. Part way done.
    [MCU.kicad_sch, audio_out.kicad_sch, midi.kicad_sch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]
2024-10-27 Finished checking all parts against LCSC IDs. Found remaining errors. Added manufacturer part numbers to all parts.
    [MCU.kicad_sch, audio_out.kicad_sch, midi.kicad_sch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]
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2024-10-27 Created Gerber files using 'gerber to order' plugin 1.0.6
    [stm-midi-poc1-B_Cu.gbr, stm-midi-poc1-B_Mask.gbr, stm-midi-poc1-B_Paste.gbp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]
2024-10-27 Created production files using Fabrication Toolkit plugin 4.5.0
    [bom.csv]
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2024-11-02 Update schematic with notes on the headphone amplifier and I2S MCK
    [audio_out.kicad_sch, stm-midi-poc1.kicad_sch]
2024-11-06 Received EVT #1 boards. Updating based on errors found so far. Added revision page. First error was misunderstanding the TRS connector pinout/schematic.
    [midi.kicad_sch, revisions.kicad_sch, stm-midi-poc1.kicad_pcb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]
2024-11-06 1. Fixed mis-wired 3.5mm jacks everywhere. 2. Use smaller opto-isolator and diode with updated circuit for one MIDI.
    [midi.kicad_sch, stm-midi-poc1.kicad_pcb, user_interface.kicad_sch]
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2024-11-07 Move MIDI1 to the new opto-isolator circuit. Update silkscreen with EVT#2.
    [midi.kicad_sch, stm-midi-poc1.kicad_pcb]
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2024-12-21 More revisions for EVT2: 1. Move GAIN0/1 to MCU pins. 2. Revise SPI header with additional screen GPIO. 3. Revise GPIO header due to 1 and 2.
    [MCU.kicad_sch, audio_out.kicad_sch, revisions.kicad_sch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]
2024-12-21 Correct 3D positioning of 2-pin header
    [stm-midi-poc1.kicad_pcb]
2024-12-21 Update schematic date and minor reposition of GND vias
    [MCU.kicad_sch, audio_out.kicad_sch, revisions.kicad_sch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]
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2024-12-21 Consolidate UART5 with 4 & 6 on a single header
    [midi.kicad_sch, revisions.kicad_sch, stm-midi-poc1.kicad_pcb]
2024-12-21 Misc cleanups: Consistent part designators, move and clean silkscreen, etc.
    [MCU.kicad_sch, stm-midi-poc1.kicad_pcb]
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2024-12-22 Add female jumper to allow experimenting with Pimoroni circuit (default 1kΩ). Minor cleanups.
    [audio_out.kicad_sch, revisions.kicad_sch, stm-midi-poc1.kicad_pcb]
2024-12-22 Prepare EVT2 for JLCPCB by replacing parts not in stock and generating necessary outputs.
    [BOM-stm-midi-poc1.csv, audio_out.kicad_sch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]
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2025-01-04 Received EVT #2 boards. Testing so far reveals no problems.
    [audio_out.kicad_sch, revisions.kicad_sch]

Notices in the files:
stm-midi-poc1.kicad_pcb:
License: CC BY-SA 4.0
